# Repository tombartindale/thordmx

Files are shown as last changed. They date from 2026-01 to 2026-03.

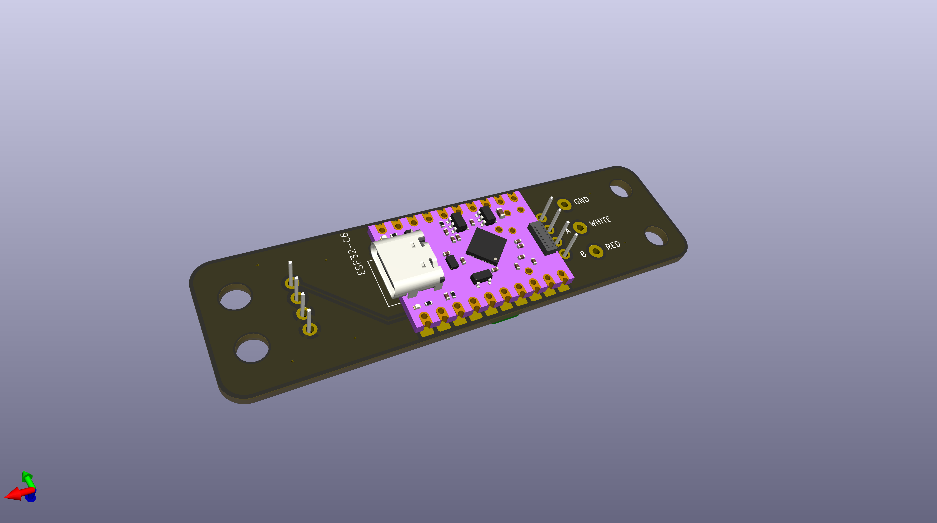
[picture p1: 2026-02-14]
docs/images/dmx_rec_bottom.png

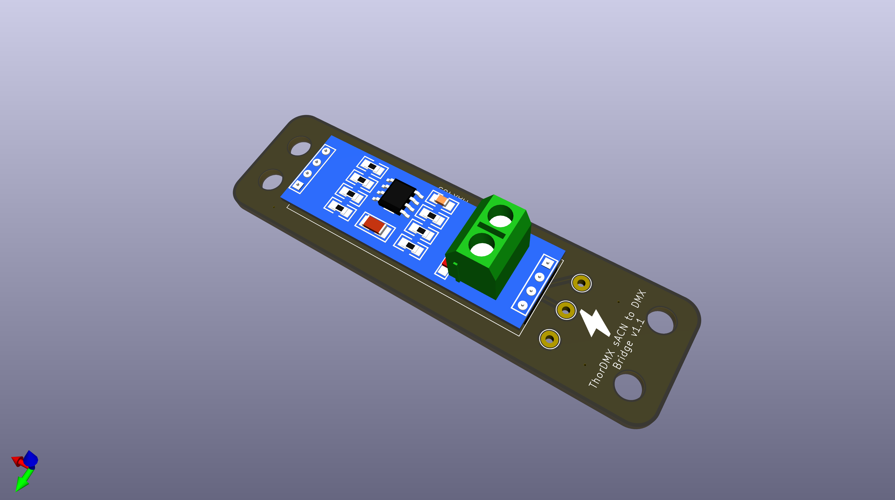
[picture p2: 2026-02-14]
docs/images/dmx_rec_top.png

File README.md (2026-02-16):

# ThorDMX Bridge System

> **Looking to build or set up a ThorDMX Bridge?** Check out the [User Documentation](https://tombartindale.github.io/thordmx/) for step-by-step guides on parts, assembly, firmware, and configuration.

A complete solution for wirelessly bridging sACN (E1.31) lighting data to DMX512 fixtures. The system consists of ESP32-based hardware devices and cross-platform management software for deploying and managing fleets of DMX bridges in professional lighting environments.

## Overview

The ThorDMX Bridge System enables lighting technicians to:

- **Receive sACN over WiFi** and output standard DMX512 signals
- **Discover and configure** multiple bridge devices from a single application
- **Provision new devices** by connecting to their WiFi access points
- **Monitor fleet health** with real-time status updates
- **Update firmware remotely** across multiple devices simultaneously

## Components

### Firmware (`/firmware`)

ESP32-C6 Arduino firmware that runs on the physical DMX bridge hardware.

**Key Features:**

- Receives sACN (E1.31) multicast packets over WiFi
- Outputs DMX512 signal via MAX485 transceiver (GPIO 0)
- Access Point mode for initial configuration with captive portal
- mDNS service advertisement (`_sacn-dmx._tcp`) for network discovery
- JSON REST API for remote configuration and monitoring
- OTA firmware updates with automatic rollback on failure
- WS2812 status LED for visual device state indication
- Serial interface for bulk provisioning during deployment

**Hardware Requirements:**

- ESP32-C6 microcontroller
- MAX485 differential transceiver for DMX output
- WS2812 RGB LED for status indication

**API Endpoints:**
| Endpoint | Method | Description |
|---|---|---|
| `/api/status` | GET | Device status and diagnostics |
| `/api/config` | GET/POST | Read or update configuration |
| `/api/reboot` | POST | Restart the device |
| `/api/identify` | POST | Flash LED for physical identification |
| `/api/firmware` | GET/POST | Firmware info and OTA updates |
| `/api/firmware/rollback` | POST | Revert to previous firmware |

---

### DMX Manager (`/dmx-manager`)

Cross-platform Electron desktop application for managing fleets of DMX bridge devices.

**Key Features:**

- **Automatic Discovery**: Finds devices on the network via mDNS
- **AP Provisioning**: Scans for unconfigured device access points and provisions them with WiFi credentials
- **Batch Configuration**: Configure multiple devices simultaneously with templated naming
- **Fleet Monitoring**: Real-time dashboard showing device health, signal strength, and sACN status
- **Remote Firmware Updates**: OTA flash multiple devices with progress tracking
- **Credential Auto-fill**: Retrieves current WiFi password from system keychain for easy provisioning

**Technology Stack:**

- Electron (cross-platform desktop)
- Vue 3 with TypeScript
- Tailwind CSS (dark mode optimized for lighting environments)
- Pinia for state management
- Native WiFi APIs (CoreWLAN on macOS, netsh on Windows, NetworkManager on Linux)

**Supported Platforms:**

- macOS 11+
- Windows 10+
- Linux (Ubuntu 20.04+)

---

### Simulator (`/simulator`)

A Node.js-based simulator for testing the DMX Manager application without physical hardware.

**Key Features:**

- Simulates multiple DMX bridge devices with full API compatibility
- mDNS service advertisement for discovery testing
- Fault injection for testing error handling scenarios
- Interactive CLI for runtime control
- Predefined scenarios for common testing situations

**Predefined Scenarios:**
| Scenario | Description |
|---|---|
| `single-device` | One healthy device |
| `three-devices` | Three devices on different universes |
| `ten-devices` | Load testing with 10 devices |
| `mixed-health` | Mix of healthy and faulty devices |
| `production-like` | Realistic 8-device deployment |
| `signal-loss` | Devices losing sACN signal |
| `high-latency` | 2-second response delays |
| `network-timeout` | Non-responsive devices |

**Quick Start:**

```bash
cd simulator
npm install
npm run dev -- --scenario three-devices
```

---

## Getting Started

### Running the Manager Application

```bash
cd dmx-manager
npm install
npm run dev
```

### Flashing Firmware to Hardware

1. Open `/firmware/DMX_Receiver` in Arduino IDE or PlatformIO
2. Select ESP32-C6 as the target board
3. Upload to your device
4. On first boot, the device creates an access point named `THOR-BRIDGE-XXXX`
5. Use the DMX Manager app to provision the device with your WiFi credentials

### Using the Simulator for Development

```bash
cd simulator
npm install
npm run dev -- --scenario production-like
```

The simulator will advertise devices via mDNS, which the DMX Manager will automatically discover.

---

## Specifications

Detailed technical specifications are available in the `/specs` directory:

- **[sacn-dmx-spec.md](specs/sacn-dmx-spec.md)** - Firmware technical specification
- **[dmx-manager-app-spec.md](specs/dmx-manager-app-spec.md)** - Manager application specification

---

## Project Structure

```
DMX_Receiver/
├── firmware/           # ESP32 Arduino firmware
│   └── DMX_Receiver/   # Main firmware sketch
├── dmx-manager/        # Electron desktop application
│   ├── electron/       # Main process (discovery, WiFi control)
│   └── src/            # Vue frontend
├── simulator/          # Device simulator for testing
│   └── src/            # Simulator source
└── specs/              # Technical specifications
```

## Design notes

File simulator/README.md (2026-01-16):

# DMX Receiver Simulator

A configurable simulator for testing the dmx-manager application. Simulates multiple DMX receiver devices with full JSON API and mDNS support, including fault injection for testing error scenarios.

## Quick Start

```bash
cd simulator
npm install
npm run dev
```

This starts 3 simulated devices by default.

## Usage

### Command Line Options

```bash
# Load a predefined scenario
npm run dev -- --scenario production-like

# Create custom number of devices
npm run dev -- --devices 10

# Custom starting port (default: 8080)
npm run dev -- --devices 5 --port 9000

# Disable mDNS (useful when running multiple simulators)
npm run dev -- --scenario three-devices --no-mdns
```

### Predefined Scenarios

| Scenario | Description | Devices |
|---|---|---|
| `single-device` | One healthy device | 1 |
| `three-devices` | Three devices on different universes | 3 |
| `ten-devices` | Load testing setup | 10 |
| `signal-loss` | Devices losing sACN signal | 2 |
| `packet-drop` | 30% packet drop rate | 2 |
| `high-latency` | 2 second response delay | 2 |
| `network-timeout` | Devices that don't respond | 2 |
| `packet-errors` | Corrupted sACN packets | 2 |
| `unstable` | Random device reboots | 2 |
| `low-memory` | Heap exhaustion simulation | 1 |
| `mixed-health` | Mix of healthy and faulty devices | 5 |
| `production-like` | Realistic 8-device setup | 8 |

### Interactive Commands

Once running, you can control the simulator interactively:

```
list                  List all devices with status
scenarios             List available scenarios
load <scenario>       Switch to a different scenario
fault <id> <type>     Inject fault on a device
clear <id>            Clear faults on a device
clear-all             Clear all faults
signal-loss <id>      Simulate sACN signal loss
restore <id>          Restore signal/network
offline <id>          Take device completely offline
add [name] [universe] Add a new device
remove <id>           Remove a device
status <id>           Show full device status JSON
exit                  Stop simulator and exit
```

### Fault Types

| Type | Effect |
|---|---|
| `signal-loss` | Device stops receiving sACN, dmx_fps drops to 0 |
| `timeout` | Device stops responding to all HTTP requests |
| `slow` | 2 second delay on all responses |
| `drop` | 30% of requests are silently dropped |
| `errors` | 10% of sACN packets are marked as errors |

## API Endpoints

Each simulated device exposes the same API as the real firmware:

| Endpoint | Method | Description |
|---|---|---|
| `/api/status` | GET | Full device status |
| `/api/config` | GET | Device configuration |
| `/api/config` | POST | Update configuration |
| `/api/reboot` | POST | Trigger device reboot |
| `/api/identify` | POST | Flash LED for identification |
| `/api/firmware` | GET | Firmware info |
| `/api/firmware` | POST | Upload firmware (multipart) |
| `/api/firmware/rollback` | POST | Rollback to previous firmware |

### Example API Calls

```bash
# Get device status
curl http://localhost:8080/api/status

# Update universe
curl -X POST http://localhost:8080/api/config \
  -H "Content-Type: application/json" \
  -d '{"sacn_universe": 5}'

# Identify device (flash LED for 10 seconds)
curl -X POST http://localhost:8080/api/identify \
  -H "Content-Type: application/json" \
  -d '{"duration": 10}'

# Reboot device
curl -X POST http://localhost:8080/api/reboot
```

## mDNS Discovery

Devices advertise themselves via mDNS as `_sacn-dmx._tcp` services.

```bash
# macOS
dns-sd -B _sacn-dmx._tcp local

# Linux
avahi-browse -rt _sacn-dmx._tcp
```

Each service includes TXT records:
- `universe` - sACN universe number
- `mac` - Device MAC address
- `version` - Firmware version

## Programmatic Usage

You can also use the simulator as a library in your tests:

```typescript
import { DmxReceiverSimulator } from './simulator.js';

const simulator = new DmxReceiverSimulator({
  basePort: 8080,
  enableMdns: true,
});

// Load a scenario
await simulator.loadScenario('three-devices');

// Or create custom devices
await simulator.addDevice({
  name: 'Test-Device',
  universe: 1,
});

// Inject faults
simulator.setDeviceFault(deviceId, {
  sacnSignalLoss: true,
});

// Clear faults
simulator.clearDeviceFault(deviceId);

// Get device info
const devices = simulator.getDevices();

// Cleanup
await simulator.stop();
simulator.destroy();
```

## Test Scenarios

### Testing Device Discovery

```bash
npm run dev -- --scenario three-devices
```

Then open dmx-manager - it should discover all 3 devices via mDNS.

### Testing Error Handling

```bash
npm run dev -- --scenario mixed-health
```

This creates 5 devices with various faults to test how the manager handles:
- Healthy devices (2)
- Signal loss (1)
- Slow responses (1)
- Packet drops (1)

### Testing Bulk Operations

```bash
npm run dev -- --devices 20
```

Use to test batch configuration updates and firmware upgrades.

### Testing Offline Recovery

```bash
# Start simulator
npm run dev -- --scenario three-devices

# Take a device offline
simulator> offline stage-left

# Verify manager shows device as offline
# Then restore it
simulator> restore stage-left
```

## Development

```bash
# Build TypeScript
npm run build

# Run from compiled JS
npm start

# Run directly with tsx
npm run dev
```

## Architecture

```
simulator/
├── src/
│   ├── index.ts           # CLI entry point
│   ├── simulator.ts       # Main simulator orchestrator
│   ├── simulated-device.ts # Device state machine
│   ├── device-server.ts   # Express HTTP server per device
│   ├── mdns-advertiser.ts # Bonjour mDNS service
│   ├── scenarios.ts       # Predefined test scenarios
│   └── types.ts           # TypeScript interfaces
├── package.json
├── tsconfig.json
└── README.md
```

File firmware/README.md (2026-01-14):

# sACN to DMX Bridge

A wireless sACN (E1.31) to DMX512 bridge built on the ESP32-C6 microcontroller. The device receives sACN packets over WiFi and outputs a standard DMX512 signal for controlling lighting fixtures.

## Features

- **WiFi Connectivity**: Automatic AP mode fallback with captive portal for easy setup
- **SmartConfig Support**: Bulk provisioning using ESP-Touch protocol
- **Serial Configuration**: Command-line interface for manufacturing and bulk deployment
- **sACN/E1.31 Reception**: Standard multicast sACN with priority handling
- **DMX512 Output**: Full 512-channel DMX at 40Hz refresh rate
- **JSON REST API**: Complete control and monitoring via HTTP
- **OTA Updates**: Over-the-air firmware updates with automatic rollback
- **mDNS Discovery**: Easy network discovery via Bonjour/Avahi
- **Status LED**: WS2812 RGB LED for visual status indication

## Hardware Requirements

- **Microcontroller**: ESP32-C6
- **DMX Output**: GPIO 0 connected to MAX485 transceiver (DI pin)
- **Status LED**: WS2812 RGB LED on GPIO 8
- **Power**: 5V USB or external power supply

## Arduino IDE Setup

### 1. Install ESP32 Board Support

1. Open Arduino IDE
2. Go to **File → Preferences**
3. Add this URL to "Additional Board Manager URLs":
   ```
   https://espressif.github.io/arduino-esp32/package_esp32_index.json
   ```
4. Go to **Tools → Board → Boards Manager**
5. Search for "esp32" and install **esp32 by Espressif Systems**
6. Select **Tools → Board → ESP32 Arduino → ESP32C6 Dev Module**

### 2. Install Required Libraries

Open **Tools → Manage Libraries** and install:

- **ArduinoJson** by Benoit Blanchon (v6.x or later)
- **FastLED** by Daniel Garcia
- **sACN** by sstaub (https://github.com/sstaub/sACN) - Install from ZIP or Git URL

**Note**: The following libraries are built-in with ESP32 Arduino core:
- WiFi
- WebServer
- ESPmDNS
- Preferences
- Update
- esp_dmx

### 3. Board Configuration

Set the following in Arduino IDE under **Tools**:

- **Board**: ESP32C6 Dev Module
- **Upload Speed**: 921600
- **USB CDC On Boot**: Enabled
- **Flash Size**: 4MB (or your board's flash size)
- **Partition Scheme**: Minimal SPIFFS (1.9MB APP with OTA/190KB SPIFFS)

## Building and Uploading

1. Open `DMX_Receiver.ino` in Arduino IDE
2. Connect your ESP32-C6 via USB
3. Select the correct COM port under **Tools → Port**
4. Click **Upload** button or press `Ctrl+U`

## First-Time Setup

### Method 1: Captive Portal (Recommended for Single Device)

1. Power on the device
2. The device will create a WiFi network named `DMX-Bridge-XXXX` (where XXXX is the last 4 digits of MAC address)
3. Connect to this network from your phone or computer
4. A configuration page should open automatically (or navigate to `192.168.4.1`)
5. Enter your WiFi credentials and desired sACN universe
6. Click "Save & Connect"
7. The device will reboot and connect to your network

### Method 2: SmartConfig (For Multiple Devices)

1. Power on all unconfigured devices
2. Download ESP-Touch app:
   - **iOS**: [EspressifTouchV2](https://apps.apple.com/app/espressif-esptouch/id1071176700)
   - **Android**: [EspTouch](https://github.com/EspressifApp/EsptouchForAndroid/releases)
3. Connect your phone to the target WiFi network
4. Open the app and enter WiFi credentials
5. Press "Confirm" to broadcast credentials
6. All devices will receive credentials and connect
7. Configure individual universe numbers via API or serial

### Method 3: Serial Configuration (For Manufacturing)

1. Connect device via USB
2. Open Serial Monitor at 115200 baud
3. Send configuration command:
   ```
   CONFIG:{"wifi_ssid":"YourNetwork","wifi_password":"password123","sacn_universe":1,"device_name":"Stage-Left"}
   ```
4. Device will save settings and reboot

#### Serial Commands

- `STATUS` - Get current device status
- `CONFIG:{json}` - Update configuration
- `REBOOT` - Restart device
- `FACTORY_RESET` - Clear all settings and reboot

## Usage

### Finding Your Device

After connecting to WiFi, find your device using:

**macOS/Linux:**
```bash
dns-sd -B _sacn-dmx._tcp local
```

**Or access directly:**
```
http://dmx-bridge-xxxx.local/api/status
```

### API Endpoints

#### GET /api/status
Returns comprehensive device status including WiFi, sACN stats, and system info.

```bash
curl http://dmx-bridge-xxxx.local/api/status
```

#### GET /api/config
Returns current configuration (WiFi SSID, universe, device name).

```bash
curl http://dmx-bridge-xxxx.local/api/config
```

#### POST /api/config
Update device configuration.

```bash
curl -X POST http://dmx-bridge-xxxx.local/api/config \
  -H "Content-Type: application/json" \
  -d '{"sacn_universe":2,"device_name":"Stage-Right"}'
```

#### POST /api/reboot
Reboot the device.

```bash
curl -X POST http://dmx-bridge-xxxx.local/api/reboot
```

#### POST /api/firmware
Upload new firmware for OTA update.

```bash
curl -X POST -F "firmware=@firmware.bin" http://dmx-bridge-xxxx.local/api/firmware
```

#### POST /api/firmware/rollback
Rollback to previous firmware version.

```bash
curl -X POST http://dmx-bridge-xxxx.local/api/firmware/rollback
```

## LED Status Indicators

| State | LED Behavior |
|---|---|
| AP mode active | Pulsing blue (1 second cycle) |
| Connecting to WiFi | Pulsing yellow (0.5 second cycle) |
| Connected successfully | Solid green for 2 seconds, then off |
| Receiving sACN | Off (normal operation) |
| WiFi connection lost | Solid red |
| SmartConfig listening | Pulsing blue |
| SmartConfig received | Two rapid green flashes |

## Troubleshooting

### Device Won't Connect to WiFi

1. Try factory reset: Send `FACTORY_RESET` via serial
2. Check WiFi credentials are correct
3. Ensure 2.4GHz network (ESP32 doesn't support 5GHz)
4. Check signal strength (should be >-70 dBm)

### No DMX Output

1. Verify MAX485 transceiver connections:
   - ESP32 GPIO 0 → MAX485 DI
   - MAX485 DE and RE tied together (to GPIO or high)
   - MAX485 A and B to DMX connector
2. Check DMX cable polarity
3. Verify sACN packets are being sent to correct universe
4. Check `/api/status` for `sacn_packets_received` counter

### Can't Access Web Interface

1. Ensure device is connected to network (LED should be off, not pulsing)
2. Try accessing by IP instead of hostname
3. Check mDNS is working: `ping dmx-bridge-xxxx.local`
4. Firewall may be blocking port 80

### OTA Update Fails

1. Ensure firmware binary is valid (.bin file from Arduino IDE)
2. Check available heap: should be >100KB free
3. Try smaller firmware or different partition scheme
4. Power cycle and try again

## Development

### Project Structure

```
DMX_Receiver/
├── DMX_Receiver.ino         # Main sketch with setup() and loop()
├── wifi_manager.ino         # WiFi and SmartConfig handling
├── serial_config.ino        # Serial command interface
├── sacn_receiver.ino        # sACN/E1.31 packet processing
├── dmx_output.ino           # DMX512 transmission
├── api_server.ino           # JSON REST API endpoints
├── captive_portal.ino       # HTML captive portal
├── led_controller.ino       # WS2812 status LED
└── README.md                # This file
```

### Task Architecture

The application uses FreeRTOS tasks for concurrent operation:

1. **WiFi Task** (Core 0) - Connection management, AP mode, SmartConfig
2. **sACN Task** (Core 1) - UDP multicast reception and parsing
3. **DMX Task** (Core 1) - DMX512 frame transmission at 40Hz
4. **LED Task** (Core 0) - Status LED animation
5. **Serial Task** (Core 0) - Serial command processing

### Memory Considerations

- DMX buffer: 512 bytes (shared between sACN and DMX tasks)
- Task stacks: ~24KB total
- HTTP server buffer: ~4KB
- sACN library: ~8KB
- Minimum free heap during operation: ~100KB

## License

This project is provided as-is for educational and commercial use.

## Credits

- **ESPAsyncE131** library by forkineye
- **FastLED** library by Daniel Garcia
- **ArduinoJson** library by Benoit Blanchon
- **esp_dmx** library (ESP32 Arduino Core)

## Support

For issues, questions, or contributions, please refer to the specification document: `sacn-dmx-spec.md`

## Version History

- **1.0.0** - Initial release
  - WiFi connectivity with AP fallback
  - SmartConfig provisioning
  - Serial configuration interface
  - sACN/E1.31 reception
  - DMX512 output
  - JSON REST API
  - OTA firmware updates
  - mDNS discovery
  - WS2812 status LED

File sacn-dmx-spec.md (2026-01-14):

# sACN to DMX Bridge — Technical Specification

## Overview

A wireless sACN (E1.31) to DMX512 bridge built on the ESP32-C6 microcontroller. The device receives sACN packets over WiFi and outputs a standard DMX512 signal for controlling lighting fixtures.

## Hardware Platform

- **Microcontroller:** ESP32-C6
- **Development framework:** Arduino (ESP32 Arduino Core)
- **DMX output pin:** GPIO 0 (directly feeds a MAX485 differential transceiver)
- **Status LED:** WS2812 RGB LED on GPIO 8

## Functional Requirements

### F1: WiFi Connectivity

- **F1.1:** On first boot or when no known network is available, the device shall enter Access Point (AP) mode.
- **F1.2:** AP mode SSID shall be `DMX-Bridge-XXXX` where `XXXX` is the last four hexadecimal digits of the device MAC address.
- **F1.3:** The AP shall be open (no password) for ease of initial configuration.
- **F1.4:** In AP mode, the device shall serve a captive portal on `192.168.4.1` presenting a web form to configure WiFi credentials and sACN universe.
- **F1.5:** Upon successful configuration, credentials shall be saved and the device shall reboot into station mode.
- **F1.6:** The device shall automatically reconnect to the configured network on subsequent power cycles.
- **F1.7:** If the configured network becomes unavailable, the device shall retry connection for 30 seconds, then fall back to AP mode.

### F1A: Serial Configuration Interface

A serial interface for bulk provisioning during manufacturing or deployment.

- **F1A.1:** The device shall listen on the USB serial port at 115200 baud for configuration commands.
- **F1A.2:** Serial configuration shall be available in all device states (AP mode, connecting, connected).
- **F1A.3:** The device shall accept a JSON configuration object as a single line of text.

**Serial command format:**
```
CONFIG:{"wifi_ssid":"NetworkName","wifi_password":"password123","sacn_universe":1,"device_name":"Stage-Left"}
```

- **F1A.4:** All fields in the JSON object are optional. Only provided fields shall be updated.
- **F1A.5:** The device shall respond with a JSON status line:

**Success response:**
```
OK:{"message":"Configuration saved","reboot_required":true}
```

**Error response:**
```
ERROR:{"message":"Invalid JSON format"}
```

- **F1A.6:** If WiFi credentials are changed, the device shall automatically reboot 2 seconds after sending the success response.
- **F1A.7:** The device shall also accept the following serial commands:
  - `STATUS` — returns current device status as JSON (same format as GET /api/status)
  - `REBOOT` — triggers immediate device restart
  - `FACTORY_RESET` — clears all saved configuration and reboots into AP mode

**Example provisioning session:**
```
> STATUS
< OK:{"device_name":"DMX-Bridge-A1B2","wifi_connected":false,"sacn_universe":1,...}
> CONFIG:{"wifi_ssid":"VenueWiFi","wifi_password":"secret","sacn_universe":5}
< OK:{"message":"Configuration saved","reboot_required":true}
< REBOOTING...
```

### F1B: SmartConfig Provisioning

Support for Espressif SmartConfig (ESP-Touch) protocol for bulk WiFi provisioning.

- **F1B.1:** When in AP mode, the device shall simultaneously listen for SmartConfig broadcasts.
- **F1B.2:** SmartConfig shall use the ESP-Touch V2 protocol (AES encrypted).
- **F1B.3:** Upon receiving valid SmartConfig credentials, the device shall:
  1. Save the WiFi credentials to NVS
  2. Flash the status LED green twice rapidly to confirm receipt
  3. Reboot and attempt connection to the provided network
- **F1B.4:** SmartConfig shall have a 2-minute timeout when in AP mode. After timeout, the device remains in AP mode and restarts SmartConfig listening.
- **F1B.5:** SmartConfig only provisions WiFi credentials. Other settings (universe, device name) must be configured via API or serial after network connection.

**LED behaviour during SmartConfig:**
| State | LED Behaviour |
|---|---|
| Listening for SmartConfig | Pulsing blue (same as AP mode) |
| SmartConfig credentials received | Two rapid green flashes, then reboot |

**Provisioning workflow for multiple devices:**
1. Power on all unconfigured devices (all enter AP mode, listening for SmartConfig)
2. Use ESP-Touch app (iOS/Android) or esptool to broadcast credentials
3. All devices receive credentials simultaneously and reboot
4. Use JSON API discovery (mDNS) to find devices and configure universes/names

### F2: sACN Reception

The device shall use the ESPAsyncE131 library (https://github.com/forkineye/ESPAsyncE131) for sACN packet handling.

- **F2.1:** The device shall listen for E1.31 (sACN) multicast packets on the standard port (5568).
- **F2.2:** The device shall subscribe to the multicast group for the configured universe (default: universe 1).
- **F2.3:** Supported universe range: 1–63999.
- **F2.4:** The device shall extract all 512 DMX channel values from received sACN packets.
- **F2.5:** The device shall handle sACN priority correctly — if packets from multiple sources are received, the highest priority source shall take precedence.
- **F2.6:** If sACN packets stop arriving, the device shall hold the last received DMX values indefinitely (no timeout fade).

**ESPAsyncE131 usage notes:**
- Use multicast mode (`E131_MULTICAST`) for standard sACN reception.
- The library handles universe subscription and multicast group joining automatically.
- Access packet data via `e131.data` array after checking `e131.isEmpty()`.
- Source name available via `e131.packet->source_name` for status reporting.

### F3: DMX Output

- **F3.1:** The device shall output a DMX512 signal conforming to ANSI E1.11 (DMX512-A).
- **F3.2:** Output shall be on GPIO 0, driving a MAX485 transceiver.
- **F3.3:** All 512 channels shall be transmitted in each DMX packet.
- **F3.4:** DMX refresh rate shall be approximately 40Hz (~25ms per frame).
- **F3.5:** DMX output shall begin immediately on boot with all channels at zero until sACN data is received.

### F3A: mDNS Discovery

The device shall advertise itself via mDNS (Bonjour/Avahi) for easy discovery on the network.

- **F3A.1:** The device shall advertise an mDNS hostname of `{device_name}.local` (e.g., `dmx-bridge-a1b2.local`).
- **F3A.2:** The device shall advertise a service of type `_sacn-dmx._tcp` on port 80.
- **F3A.3:** The service TXT record shall include:
  - `universe={configured_universe}` — current sACN universe
  - `mac={mac_address}` — device MAC address
  - `version={firmware_version}` — firmware version string

**Example mDNS advertisement:**
```
Service: _sacn-dmx._tcp.local
Host: dmx-bridge-a1b2.local
Port: 80
TXT: universe=1, mac=AA:BB:CC:DD:A1:B2, version=1.0.0
```

- **F3A.4:** mDNS shall be active whenever the device is connected to WiFi in station mode.
- **F3A.5:** The hostname shall update if the device name is changed (requires reboot).

**Discovery commands:**

On macOS/Linux:
```bash
dns-sd -B _sacn-dmx._tcp local
# or
avahi-browse -rt _sacn-dmx._tcp
```

On Windows (with Bonjour installed):
```bash
dns-sd -B _sacn-dmx._tcp local
```

**Programmatic discovery (Python example):**
```python
from zeroconf import ServiceBrowser, Zeroconf

class Listener:
    def add_service(self, zc, type, name):
        info = zc.get_service_info(type, name)
        print(f"Found: {info.server} at {info.parsed_addresses()[0]}")
        print(f"  Universe: {info.properties[b'universe'].decode()}")

zeroconf = Zeroconf()
browser = ServiceBrowser(zeroconf, "_sacn-dmx._tcp.local.", Listener())
```

### F4: Configuration Persistence

- **F4.1:** All configuration settings shall be stored in non-volatile storage (NVS/flash).
- **F4.2:** Persisted settings include:
  - WiFi SSID
  - WiFi password
  - sACN universe number
  - Device name
- **F4.3:** Settings shall survive power cycles and firmware updates where possible.

### F5: JSON API

The device shall expose an HTTP JSON API on port 80 when connected to WiFi in station mode.

#### F5.1: GET /api/status

Returns current device status including diagnostic information.

**Response:**
```json
{
  "device_name": "DMX-Bridge-A1B2",
  "firmware_version": "1.0.0",
  "wifi_connected": true,
  "wifi_ssid": "LightingNetwork",
  "wifi_rssi": -52,
  "wifi_signal_quality": "good",
  "ip_address": "192.168.1.50",
  "mac_address": "AA:BB:CC:DD:A1:B2",
  "sacn_universe": 1,
  "sacn_packets_received": 123456,
  "sacn_packets_errors": 12,
  "sacn_source_ip": "192.168.1.10",
  "sacn_source_name": "ETC Eos",
  "sacn_priority": 100,
  "last_packet_ms_ago": 12,
  "dmx_fps": 40,
  "uptime_seconds": 3600,
  "free_heap_bytes": 180000,
  "min_free_heap_bytes": 165000,
  "cpu_temperature_c": 42.5,
  "reboot_count": 3,
  "last_reboot_reason": "power_on"
}
```

**Field descriptions:**

| Field | Description |
|---|---|
| `wifi_rssi` | WiFi signal strength in dBm (typical range: -30 excellent to -90 poor) |
| `wifi_signal_quality` | Human-readable signal quality: "excellent" (>-50), "good" (-50 to -60), "fair" (-60 to -70), "poor" (<-70) |
| `sacn_packets_errors` | Count of malformed or dropped sACN packets since boot |
| `sacn_priority` | Priority value from current sACN source (0-200) |
| `dmx_fps` | Actual DMX output frames per second (rolling average) |
| `free_heap_bytes` | Current free heap memory in bytes |
| `min_free_heap_bytes` | Lowest free heap since boot (indicates memory pressure) |
| `cpu_temperature_c` | ESP32 internal temperature sensor reading (if available) |
| `reboot_count` | Number of reboots since factory reset (stored in NVS) |
| `last_reboot_reason` | Reason for last reboot: "power_on", "software", "watchdog", "crash", "brownout" |

#### F5.2: GET /api/config

Returns current configuration.

**Response:**
```json
{
  "device_name": "DMX-Bridge-A1B2",
  "sacn_universe": 1,
  "wifi_ssid": "LightingNetwork"
}
```

Note: WiFi password shall never be returned by the API.

#### F5.3: POST /api/config

Batch update configuration settings.

**Request body (all fields optional):**
```json
{
  "device_name": "Stage-Left-DMX",
  "sacn_universe": 2,
  "wifi_ssid": "NewNetwork",
  "wifi_password": "newpassword123"
}
```

**Response:**
```json
{
  "success": true,
  "message": "Configuration updated. Reboot required for WiFi changes.",
  "reboot_required": true
}
```

**Validation:**
- `sacn_universe`: integer, 1–63999
- `device_name`: string, 1–32 characters, alphanumeric and hyphens only
- `wifi_ssid`: string, 1–32 characters
- `wifi_password`: string, 8–63 characters (WPA2 requirement)

#### F5.4: POST /api/reboot

Triggers a device restart.

**Request body:** None required.

**Response:**
```json
{
  "success": true,
  "message": "Rebooting in 1 second."
}
```

The device shall delay 1 second before rebooting to allow the HTTP response to complete.

#### F5.5: POST /api/firmware

Upload new firmware binary to update the device.

**Request:**
- Content-Type: `multipart/form-data`
- Field name: `firmware`
- File: compiled firmware binary (.bin file)

**Example using curl:**
```bash
curl -X POST -F "firmware=@firmware_v1.1.0.bin" http://dmx-bridge-a1b2.local/api/firmware
```

**Response (success):**
```json
{
  "success": true,
  "message": "Firmware uploaded successfully. Validating...",
  "new_version": "1.1.0",
  "previous_version": "1.0.0",
  "rebooting": true
}
```

**Response (validation failed):**
```json
{
  "success": false,
  "error": "Firmware validation failed: invalid magic bytes"
}
```

**Update process:**
1. Device receives firmware binary and writes to OTA partition.
2. Device validates firmware (magic bytes, size, checksum if available).
3. If valid, device marks new partition as bootable and stores current version for rollback.
4. Device responds with success and reboots after 2 seconds.
5. On first boot after update, device runs self-test (WiFi connects, DMX output starts).
6. If self-test passes, update is marked as confirmed.
7. If self-test fails or device crashes within 60 seconds, watchdog triggers rollback.

**Validation checks:**
- Firmware binary has valid ESP32 application header
- Binary size is within flash partition limits
- Optional: SHA256 checksum if provided in request

#### F5.6: POST /api/firmware/rollback

Manually trigger a rollback to the previous firmware version.

**Request body:** None required.

**Response (success):**
```json
{
  "success": true,
  "message": "Rolling back to previous firmware",
  "current_version": "1.1.0",
  "rollback_version": "1.0.0",
  "rebooting": true
}
```

**Response (no rollback available):**
```json
{
  "success": false,
  "error": "No previous firmware available for rollback"
}
```

#### F5.7: GET /api/firmware

Returns current firmware information and rollback status.

**Response:**
```json
{
  "current_version": "1.1.0",
  "previous_version": "1.0.0",
  "rollback_available": true,
  "last_update": "2024-01-15T14:32:00Z",
  "update_confirmed": true,
  "partition_scheme": "ota_0 (active), ota_1 (previous)"
}
```

#### F5.8: API Error Handling

All error responses shall use appropriate HTTP status codes and include a JSON body:

```json
{
  "success": false,
  "error": "Invalid universe number. Must be 1-63999."
}
```

| Scenario | HTTP Status |
|---|---|
| Malformed JSON | 400 |
| Invalid parameter value | 400 |
| Endpoint not found | 404 |
| Internal error | 500 |

### F6: Status LED Behaviour

The WS2812 LED on GPIO 8 shall indicate device state as follows:

| State | LED Behaviour |
|---|---|
| AP mode active | Pulsing blue (1 second cycle) |
| Connecting to WiFi | Pulsing yellow (0.5 second cycle) |
| Connected, awaiting first sACN packet | Solid green for 2 seconds, then off |
| Receiving sACN normally | Off |
| WiFi connection lost | Solid red until reconnected or AP mode entered |
| Error (unrecoverable) | Fast flashing red (4Hz) |

**Rationale:** In normal installed operation, the LED remains off to avoid unwanted light pollution in performance environments.

### F7: Captive Portal Web Interface

The captive portal served in AP mode shall provide a minimal, functional HTML form.

#### F7.1: Page Structure

- Device name/identifier displayed at top
- Current firmware version displayed
- Form fields:
  - WiFi SSID (text input, required)
  - WiFi Password (password input, required)
  - sACN Universe (number input, default 1, range 1–63999)
- Submit button labelled "Save & Connect"

#### F7.2: Behaviour

- On submission, validate inputs client-side where practical.
- Display success message and indicate device will reboot.
- Device saves settings and reboots after 2 seconds.

#### F7.3: Styling

- Simple, functional appearance suitable for mobile browsers.
- No external CSS or JavaScript dependencies (fully self-contained).

## Non-Functional Requirements

### NF1: Performance

- **NF1.1:** sACN packet processing latency shall be <5ms from packet receipt to DMX output update.
- **NF1.2:** The device shall handle sACN packets at up to 44Hz without packet loss.
- **NF1.3:** DMX output shall be jitter-free under normal operation.

### NF2: Reliability

- **NF2.1:** The device shall operate continuously without requiring manual restart.
- **NF2.2:** The device shall recover gracefully from temporary WiFi dropouts.
- **NF2.3:** Watchdog timer shall be enabled to recover from software hangs.

### NF3: Memory

- **NF3.1:** RAM usage shall remain stable over time (no memory leaks).
- **NF3.2:** The application shall fit within the ESP32-C6 flash constraints.
- **NF3.3:** Flash partition layout shall include two OTA partitions for firmware updates and rollback capability.

## Software Architecture

### Recommended Task Structure

The application should use FreeRTOS tasks (available via Arduino ESP32 core):

1. **WiFi Management Task** — handles connection, reconnection, AP mode fallback, and SmartConfig listening.
2. **sACN Receiver Task** — listens for UDP multicast, parses E1.31 packets, updates DMX buffer.
3. **DMX Output Task** — continuously transmits DMX frames from buffer at 40Hz.
4. **HTTP Server Task** — serves API endpoints and captive portal.
5. **LED Controller Task** — manages WS2812 status indication.
6. **Serial Command Task** — monitors USB serial for configuration commands.

### Shared Data

- A 512-byte DMX channel buffer shared between sACN receiver and DMX output.
- Use mutex or atomic operations to prevent torn reads/writes.

### Recommended Libraries

| Function | Suggested Library |
|---|---|
| WiFi & AP mode | Built-in WiFi.h |
| SmartConfig | Built-in WiFi.h (WiFi.beginSmartConfig()) |
| mDNS | ESPmDNS (built-in) |
| HTTP server | WebServer (built-in) or ESPAsyncWebServer |
| NVS storage | Preferences.h (built-in) |
| WS2812 LED | Adafruit NeoPixel or FastLED |
| sACN/E1.31 | ESPAsyncE131 (https://github.com/forkineye/ESPAsyncE131) |
| DMX output | esp_dmx or manual UART configuration |

Note: Evaluate library compatibility with ESP32-C6 specifically, as some older libraries may not support this chip.

## Pin Assignment Summary

| GPIO | Function |
|---|---|
| 0 | DMX output (TX to MAX485 DI pin) |
| 8 | WS2812 status LED data |

## Configuration Defaults

| Parameter | Default Value |
|---|---|
| sACN Universe | 1 |
| Device Name | `DMX-Bridge-XXXX` (from MAC) |
| DMX Refresh Rate | 40Hz |
| AP Mode IP | 192.168.4.1 |
| API Port | 80 |

## Testing Criteria

### TC1: WiFi Provisioning
- [ ] Device enters AP mode on first boot.
- [ ] Captive portal is accessible at 192.168.4.1.
- [ ] WiFi credentials can be submitted and are saved.
- [ ] Device connects to configured network after reboot.
- [ ] Device falls back to AP mode if configured network unavailable.

### TC1A: Serial Configuration
- [ ] Device accepts CONFIG command with valid JSON.
- [ ] Device rejects malformed JSON with appropriate error.
- [ ] STATUS command returns current device state.
- [ ] REBOOT command triggers restart.
- [ ] FACTORY_RESET clears all config and enters AP mode.
- [ ] Partial configuration updates only specified fields.
- [ ] Serial commands work in all device states.

### TC1B: SmartConfig Provisioning
- [ ] Device listens for SmartConfig while in AP mode.
- [ ] Device receives credentials from ESP-Touch app.
- [ ] LED flashes green twice on successful SmartConfig receipt.
- [ ] Device connects to network after SmartConfig provisioning.
- [ ] Multiple devices can be provisioned simultaneously.

### TC2: sACN Reception
- [ ] Device receives sACN packets on configured universe.
- [ ] Changing universe via API updates subscription correctly.
- [ ] Device handles standard sACN sources (ETC Eos, QLC+, etc.).
- [ ] Priority handling works when multiple sources transmit.

### TC3: DMX Output
- [ ] DMX output is valid per E1.11 (test with DMX analyser).
- [ ] All 512 channels are transmitted.
- [ ] Output updates promptly when sACN data changes.
- [ ] Output holds last values when sACN stops.

### TC4: JSON API
- [ ] GET /api/status returns correct information.
- [ ] GET /api/config returns current settings.
- [ ] POST /api/config updates settings correctly.
- [ ] POST /api/reboot triggers restart.
- [ ] Invalid requests return appropriate errors.

### TC5: Status LED
- [ ] LED pulses blue in AP mode.
- [ ] LED pulses yellow while connecting.
- [ ] LED shows green briefly on connection, then turns off.
- [ ] LED remains off during normal operation.
- [ ] LED shows red on connection loss.

## Future Considerations (Out of Scope)

The following features are not included in this specification but may be considered for future versions:

- RDM passthrough
- Multiple universe output
- Art-Net input support
- Static IP configuration
- Web-based DMX monitor/debug view
- Pull-based firmware updates (device fetches from URL)
- Log streaming endpoint for remote debugging

---

*Specification version: 1.0*
*Target platform: ESP32-C6 with Arduino framework*

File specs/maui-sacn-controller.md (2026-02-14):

# sACN Color Controller - .NET MAUI App Spec

## Overview

A minimal Android app built with .NET MAUI that sends sACN (E1.31) data to DMX receivers on the local network. The app presents a color wheel for selecting an RGB color, which is transmitted as channels 1 (Red), 2 (Green), and 3 (Blue) on universe 1.

## Platform

- **Framework:** .NET MAUI (.NET 8+)
- **Target:** Android (API 24+)
- **Future:** iOS support may be added later; keep platform-specific code isolated
- **IDE:** Visual Studio Code

## Development Environment

### Prerequisites

- .NET 8 SDK (or later)
- Android SDK (API 24+) — installed via Android SDK Manager or `dotnet workload install maui-android`
- Java JDK 17 (required by Android SDK tooling)

### VS Code Extensions

| Extension | ID | Purpose |
|---|---|---|
| C# Dev Kit | `ms-dotnettools.csdevkit` | Core C# language support, project system, solution explorer |
| .NET MAUI | `ms-dotnettools.dotnet-maui` | MAUI project templates, XAML IntelliSense, device targeting, debug/deploy |
| XAML | `ms-dotnettools.vscode-dotnet-runtime` | .NET runtime acquisition (dependency of above) |

### Workload Setup

```bash
dotnet workload install maui-android
```

### Build & Run

```bash
# Build
dotnet build -f net8.0-android

# Deploy to connected device / emulator
dotnet build -f net8.0-android -t:Run
```

### Debugging

- Use the **.NET MAUI** debug launch configuration in VS Code (provided by the MAUI extension)
- Select the target Android device/emulator from the MAUI device picker in the status bar

## Core Features

### 1. Color Wheel Input

- Full-screen color wheel (or color disc) as the primary UI element
- Touch-driven: drag finger across the wheel to select hue/saturation, with a brightness slider alongside
- Selection updates continuously as the user drags (no submit button)
- Display the selected color as a preview swatch and show the RGB values (0–255) as text beneath the wheel
- Responsive to screen size; wheel should fill available width

### 2. sACN Output

- Transmit E1.31 (sACN) multicast UDP packets on the standard multicast address for universe 1: `239.255.0.1`
- Port: `5568`
- Protocol details:
  - E1.31 data packet (vector `0x00000004`)
  - Root layer, framing layer, DMP layer per ANSI E1.31-2018
  - Universe: `1`
  - Priority: `100` (default)
  - Channel data: 512 bytes (slots), only slots 1–3 populated (R, G, B), remainder zero
  - Sequence number: increment per packet (0–255, wrapping)
  - Source name: `"MAUI sACN Controller"` (UTF-8, 64 bytes padded)
  - CID: generate once on first launch, persist in app preferences
- **Transmission rate:** send packets at ~22 Hz (every ~45 ms) while the color is changing, drop to ~1 Hz keep-alive when idle (no touch for >1 second)
- Use `System.Net.Sockets.UdpClient` for multicast UDP

### 3. Network Status Warning

- On launch and on resume, check for active Wi-Fi connectivity using MAUI's `Connectivity` API (`NetworkAccess` and `ConnectionProfiles`)
- If no Wi-Fi connection is detected, show a non-dismissable banner at the top of the screen: **"No Wi-Fi connection — sACN output disabled"**
- Disable packet transmission while Wi-Fi is unavailable
- Subscribe to `Connectivity.ConnectivityChanged` to update the banner in real time
- When Wi-Fi reconnects, dismiss the banner and resume transmission

## UI Layout

```
┌─────────────────────────────┐
│ ⚠ No Wi-Fi (if applicable) │  <- warning banner (yellow/orange)
├─────────────────────────────┤
│                             │
│                             │
│        Color Wheel          │  <- touch-interactive disc
│        (hue + sat)          │
│                             │
│                             │
├─────────────────────────────┤
│  ☀ Brightness Slider        │  <- horizontal slider (0–100%)
├─────────────────────────────┤
│  ┌──────┐  R: 255           │
│  │preview│  G: 128           │  <- color swatch + RGB readout
│  │swatch │  B: 0             │
│  └──────┘                   │
└─────────────────────────────┘
```

- Single page, no navigation
- Dark background (`#1E1E1E`) so colors stand out
- Minimal chrome — the color wheel is the hero element

## Project Structure

```
SacnController/
├── SacnController.csproj
├── App.xaml / App.xaml.cs
├── MauiProgram.cs
├── MainPage.xaml / MainPage.xaml.cs
├── Services/
│   ├── SacnService.cs            # packet building & UDP transmission
│   └── NetworkMonitorService.cs  # Wi-Fi connectivity monitoring
├── Controls/
│   └── ColorWheelView.cs         # custom SkiaSharp drawable for the wheel
├── Models/
│   └── RgbColor.cs               # simple R, G, B byte struct
├── Platforms/
│   └── Android/
│       └── AndroidManifest.xml
└── Resources/
```

## Dependencies

| Package | Purpose |
|---|---|
| `SkiaSharp.Views.Maui.Controls` | Rendering the color wheel via `SKCanvasView` + touch handling |
| None (built-in) | `System.Net.Sockets.UdpClient` for sACN UDP multicast |
| None (built-in) | `Microsoft.Maui.Networking.Connectivity` for Wi-Fi detection |

No third-party sACN library — the protocol is simple enough to implement directly in `SacnService`.

## Key Implementation Notes

### Color Wheel (SkiaSharp)

- Draw a circular HSV color disc using a sweep gradient (hue) combined with a radial gradient (saturation)
- Handle `SKTouchAction.Pressed`, `Moved`, `Released` to track finger position
- Convert polar coordinates (angle → hue, distance from center → saturation) to HSV, then combine with the brightness slider value to produce RGB
- Fire a `ColorChanged` event on every touch move

### sACN Packet Structure

Total packet size: 638 bytes (126 byte header + 512 slots). Build as a `byte[]`:

| Offset | Length | Field |
|---|---|---|
| 0–11 | 12 | Preamble + post-amble + ACN packet identifier |
| 12–15 | 4 | Root flags + length |
| 16–19 | 4 | Root vector (`0x00000004`) |
| 20–35 | 16 | CID (sender UUID) |
| 36–37 | 2 | Framing flags + length |
| 38–41 | 4 | Framing vector (`0x00000002`) |
| 42–105 | 64 | Source name (UTF-8 padded) |
| 106 | 1 | Priority (100) |
| 107–108 | 2 | Sync address (0) |
| 109 | 1 | Sequence number |
| 110 | 1 | Options |
| 111–112 | 2 | Universe (1) |
| 113–114 | 2 | DMP flags + length |
| 115 | 1 | DMP vector (`0x02`) |
| 116 | 1 | Address type (`0xA1`) |
| 117–118 | 2 | First property address (0) |
| 119–120 | 2 | Address increment (1) |
| 121–122 | 2 | Property value count (513) |
| 123 | 1 | DMX start code (0) |
| 124–635 | 512 | DMX channel data (slot 1 = R, 2 = G, 3 = B) |

### Android Permissions

In `AndroidManifest.xml`:
```xml
<uses-permission android:name="android.permission.INTERNET" />
<uses-permission android:name="android.permission.ACCESS_NETWORK_STATE" />
<uses-permission android:name="android.permission.ACCESS_WIFI_STATE" />
<uses-permission android:name="android.permission.CHANGE_WIFI_MULTICAST_STATE" />
```

Acquire a `WifiManager.MulticastLock` on Android to ensure multicast packets are not dropped by the Wi-Fi driver. Acquire on app resume, release on pause.

### Transmission Lifecycle

- Start sending when the app enters the foreground and Wi-Fi is available
- Use a background `Task` with a `PeriodicTimer` for the send loop
- While touch is active: send at ~22 Hz
- While idle: send at ~1 Hz (keep-alive to prevent receivers from timing out)
- Stop sending when the app enters the background or Wi-Fi is lost
- On app close/background: stop sending (receivers retain last received values)

## CI/CD — GitHub Actions

### Workflow: Build & Release on Tag Push

**Trigger:** Push of a tag matching `v*` (e.g. `v1.0.0`)

**File:** `.github/workflows/build-android.yml`

```yaml
name: Build Android APK

on:
  push:
    tags:
      - 'v*'

jobs:
  build:
    runs-on: ubuntu-latest

    steps:
      - name: Checkout
        uses: actions/checkout@v4

      - name: Setup .NET
        uses: actions/setup-dotnet@v4
        with:
          dotnet-version: '8.0.x'

      - name: Install MAUI workload
        run: dotnet workload install maui-android

      - name: Setup Java JDK
        uses: actions/setup-java@v4
        with:
          distribution: 'microsoft'
          java-version: '17'

      - name: Restore dependencies
        run: dotnet restore SacnController/SacnController.csproj

      - name: Decode keystore
        run: echo "${{ secrets.ANDROID_KEYSTORE_B64 }}" | base64 -d > ${{ github.workspace }}/keystore.jks

      - name: Publish signed APK
        run: |
          dotnet publish SacnController/SacnController.csproj \
            -f net8.0-android \
            -c Release \
            -p:AndroidKeyStore=true \
            -p:AndroidSigningKeyStore=${{ github.workspace }}/keystore.jks \
            -p:AndroidSigningKeyAlias=${{ secrets.ANDROID_KEY_ALIAS }} \
            -p:AndroidSigningKeyPass=${{ secrets.ANDROID_KEY_PASSWORD }} \
            -p:AndroidSigningStorePass=${{ secrets.ANDROID_KEYSTORE_PASSWORD }}

      - name: Find APK
        id: find_apk
        run: |
          APK_PATH=$(find . -name '*.apk' -path '*/publish/*' | head -1)
          echo "apk_path=$APK_PATH" >> $GITHUB_OUTPUT
          echo "apk_name=$(basename $APK_PATH)" >> $GITHUB_OUTPUT

      - name: Create GitHub Release
        uses: softprops/action-gh-release@v2
        with:
          files: ${{ steps.find_apk.outputs.apk_path }}
          generate_release_notes: true
        env:
          GITHUB_TOKEN: ${{ secrets.GITHUB_TOKEN }}
```

### Required Repository Secrets

| Secret | Description |
|---|---|
| `ANDROID_KEYSTORE_B64` | Base64-encoded `.jks` keystore file (`base64 -w0 keystore.jks`) |
| `ANDROID_KEY_ALIAS` | Key alias within the keystore |
| `ANDROID_KEY_PASSWORD` | Password for the key |
| `ANDROID_KEYSTORE_PASSWORD` | Password for the keystore |

### Keystore Generation (one-time)

```bash
keytool -genkeypair -v \
  -keystore sacn-controller.jks \
  -keyalg RSA -keysize 2048 -validity 10000 \
  -alias sacn-controller \
  -storepass <password> -keypass <password>

# Encode for the secret
base64 -w0 sacn-controller.jks | pbcopy
```

### Notes

- The workflow produces a signed release APK attached to a GitHub Release
- Release notes are auto-generated from commits since the previous tag
- The APK is not uploaded to Google Play — this is a sideload-only distribution for now
- If the app project path differs from `SacnController/`, update the path in the workflow accordingly

## Out of Scope (for now)

- Multiple universes or arbitrary channel mapping
- Fixture profiles / patching
- Scene saving / recall
- Discovery (receivers are pre-configured)
- iOS build target
- Settings screen

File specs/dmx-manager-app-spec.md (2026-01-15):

# DMX Bridge Manager Application Specification

## 1. Overview

### 1.1 Purpose
A cross-platform web application for managing fleets of ESP32 sACN-to-DMX bridge devices. The application enables technicians to discover, configure, monitor, debug, and update multiple devices from a single interface.

### 1.2 Target Users
- Lighting technicians deploying multiple DMX bridges in venues
- System integrators managing device fleets
- Developers debugging device firmware

### 1.3 Key Capabilities
- **Device Discovery**: Automatic mDNS-based discovery of all DMX bridges on the network
- **Batch Configuration**: Configure multiple devices simultaneously (universe, name, WiFi)
- **Fleet Status Monitoring**: Real-time dashboard showing health of all devices
- **Remote Firmware Updates**: OTA flash multiple devices in parallel
- **Debugging Tools**: Live device metrics, packet statistics, and log viewing

---

## 2. Architecture

### 2.1 Technology Stack

| Component | Technology | Rationale |
|---|---|---|
| Runtime | Node.js 20+ | Cross-platform, excellent network libraries |
| Framework | Electron or local web server | Native app feel with web technologies |
| Frontend | Vue 3 with TypeScript | Composition API, reactive, type-safe UI |
| Styling | Tailwind CSS | Rapid UI development, dark mode support |
| State | Pinia | Official Vue store, devtools integration |
| mDNS | bonjour-service (Node.js) | Cross-platform service discovery |
| HTTP Client | Axios or fetch | Device API communication |
| Build | Vite | First-class Vue support, fast HMR |

### 2.2 Deployment Options

**Option A: Electron Desktop App (Recommended)**
- Single executable for Windows, macOS, Linux
- Native mDNS access without browser restrictions
- File system access for firmware binaries
- Tray icon for background monitoring

**Option B: Local Web Server**
- Node.js backend with Express
- React frontend served locally
- Access via `http://localhost:3000`
- Requires Node.js installation

### 2.3 System Diagram

```
┌─────────────────────────────────────────────────────────────────┐
│                    DMX Bridge Manager App                        │
├─────────────────────────────────────────────────────────────────┤
│  ┌─────────────┐ ┌─────────────┐ ┌─────────────┐ ┌───────────┐ │
│  │  Discovery  │ │  Device API │ │  Firmware   │ │   WiFi    │ │
│  │  Service    │ │  Client     │ │  Uploader   │ │ Provision │ │
│  │  (mDNS)     │ │  (HTTP/JSON)│ │  (Multipart)│ │ (Native)  │ │
│  └──────┬──────┘ └──────┬──────┘ └──────┬──────┘ └─────┬─────┘ │
│         │               │               │              │        │
│         └───────────────┴───────────────┴──────────────┘        │
│                                │                                 │
│  ┌─────────────────────────────┴─────────────────────────────┐  │
│  │                     Vue UI Layer                         │  │
│  │  ┌──────────┐ ┌──────────┐ ┌──────────┐ ┌──────────────┐  │  │
│  │  │ Device   │ │ Config   │ │ Firmware │ │ Provisioning │  │  │
│  │  │ List     │ │ Panel    │ │ Manager  │ │ Wizard       │  │  │
│  │  └──────────┘ └──────────┘ └──────────┘ └──────────────┘  │  │
│  └───────────────────────────────────────────────────────────┘  │
└─────────────────────────────────────────────────────────────────┘
                                │
                    ┌───────────┴───────────┐
                    │   Local Network       │
                    │   (WiFi/Ethernet)     │
                    └───────────┬───────────┘
                                │
        ┌───────────────────────┼───────────────────────┐
        │                       │                       │
   ┌────┴────┐            ┌────┴────┐            ┌────┴────┐
   │ DMX     │            │ DMX     │            │ DMX     │
   │ Bridge  │            │ Bridge  │            │ Bridge  │
   │ Device 1│            │ Device 2│            │ Device N│
   └─────────┘            └─────────┘            └─────────┘
```

---

## 3. Features & Functional Requirements

### 3.1 Device Discovery

#### 3.1.1 Automatic Discovery (Network Mode)
- Continuously browse for `_sacn-dmx._tcp` mDNS services
- Parse TXT records for universe, MAC, and firmware version
- Resolve IP addresses and hostnames
- Display devices within 2 seconds of appearing on network

#### 3.1.2 AP Discovery & Provisioning
Discover and provision unconfigured devices that are broadcasting their own WiFi access points.

**AP Network Pattern**
- Default device AP SSID format: `DMX-Bridge-XXXX` (where XXXX is last 4 hex digits of MAC)
- Configurable pattern matching: `DMX-Bridge-*` (glob) or `DMX-Bridge-[A-F0-9]{4}` (regex)
- AP has no password by default
- Device IP in AP mode: `192.168.4.1`

**Discovery Process**
1. Scan for WiFi networks matching the configured pattern
2. Display list of discovered AP networks with signal strength
3. User selects which APs to provision (multi-select)
4. Application connects to each AP sequentially and retrieves device info

**Provisioning Workflow**
```
┌─────────────────────────────────────────────────────────────────┐
│                    AP Provisioning Wizard                        │
├─────────────────────────────────────────────────────────────────┤
│                                                                  │
│  Step 1: Scan for Device APs                                    │
│  ┌────────────────────────────────────────────────────────────┐ │
│  │  Pattern: [DMX-Bridge-*        ]  [Scan Networks]          │ │
│  └────────────────────────────────────────────────────────────┘ │
│                                                                  │
│  Found 3 device access points:                                  │
│  ┌────────────────────────────────────────────────────────────┐ │
│  │  ☑ DMX-Bridge-A1B2    -45 dBm  ████████░░  Excellent       │ │
│  │  ☑ DMX-Bridge-C3D4    -62 dBm  █████░░░░░  Good            │ │
│  │  ☑ DMX-Bridge-E5F6    -78 dBm  ██░░░░░░░░  Fair            │ │
│  └────────────────────────────────────────────────────────────┘ │
│                                                                  │
│  Step 2: Configure WiFi Credentials                             │
│  ┌────────────────────────────────────────────────────────────┐ │
│  │  Target Network SSID:     [VenueWiFi                    ]  │ │
│  │  Target Network Password: [••••••••••••                 ]  │ │
│  └────────────────────────────────────────────────────────────┘ │
│                                                                  │
│  Step 3: Device Configuration (Optional)                        │
│  ┌────────────────────────────────────────────────────────────┐ │
│  │  Device Name Template:    [Stage-{n}                    ]  │ │
│  │  sACN Universe:           [1         ]                     │ │
│  └────────────────────────────────────────────────────────────┘ │
│                                                                  │
│                              [Cancel]  [Provision 3 Devices]    │
└─────────────────────────────────────────────────────────────────┘
```

**Per-Device Provisioning Sequence**
For each selected device AP:
1. **Disconnect** from current WiFi network
2. **Connect** to device AP (e.g., `DMX-Bridge-A1B2`)
3. **Verify** connection by fetching `GET http://192.168.4.1/api/status`
4. **Configure** device via `POST http://192.168.4.1/api/config`:
   - WiFi SSID and password (required)
   - Device name (from template)
   - sACN universe (from sequence)
5. **Wait** for device to reboot and connect to target network
6. **Reconnect** to original/target network
7. **Verify** device appears on network via mDNS discovery
8. **Repeat** for next device

**Provisioning Progress UI**
```
┌─────────────────────────────────────────────────────────────────┐
│                    Provisioning Progress                         │
├─────────────────────────────────────────────────────────────────┤
│                                                                  │
│  Overall: ████████████░░░░░░░░  2/3 devices (67%)               │
│                                                                  │
│  ✓ DMX-Bridge-A1B2 → Stage-1                                    │
│    Connected to network, universe 1                             │
│                                                                  │
│  ● DMX-Bridge-C3D4 → Stage-2                          [Working] │
│    ├─ ✓ Connected to device AP                                  │
│    ├─ ✓ Retrieved device info                                   │
│    ├─ ✓ Sent configuration                                      │
│    ├─ ○ Waiting for device reboot...                            │
│    └─ ○ Verifying on target network                             │
│                                                                  │
│  ○ DMX-Bridge-E5F6 → Stage-3                          [Pending] │
│                                                                  │
│                                            [Cancel Remaining]    │
└─────────────────────────────────────────────────────────────────┘
```

**Platform Requirements**
- **Electron (Required)**: Native WiFi scanning and connection requires OS-level APIs
  - macOS: CoreWLAN framework via native Node addon
  - Windows: WlanAPI via native Node addon
  - Linux: NetworkManager D-Bus API or iwlist
- **Library**: `node-wifi` or custom native bindings
- **Permissions**: May require administrator/root privileges for WiFi control

**Error Handling**
| Error | Recovery |
|---|---|
| Cannot connect to device AP | Skip device, add to retry list |
| Device API unreachable at 192.168.4.1 | Retry connection, then skip |
| WiFi credentials rejected by target network | Abort provisioning, notify user |
| Device doesn't appear on target network | Wait longer (30s timeout), then mark as failed |
| Lost connection during provisioning | Attempt to reconnect and resume |

**Provisioning Templates**
Save and reuse provisioning configurations:
```typescript
interface ProvisioningTemplate {
  name: string;                    // Template name
  apPattern: string;               // AP SSID pattern (glob or regex)
  targetSsid: string;              // Target WiFi network
  targetPassword?: string;         // Optionally save password (encrypted)
  deviceNameTemplate: string;      // e.g., "Stage-{n}"
  sacnUniverse: number;            // Same universe for all devices
}
```

#### 3.1.3 Manual Discovery
- Add device by IP address or hostname
- Support for devices on different subnets (with known IP)
- Persist manually added devices between sessions

#### 3.1.4 Device List
- Show all discovered devices in sortable table
- Columns: Name, IP, Universe, Status, Signal, Firmware
- Visual indicators: Online (green), Offline (red), Updating (yellow)
- Filter by: Online/Offline, Universe, Firmware version
- Search by device name or IP

### 3.2 Batch Configuration

#### 3.2.1 Multi-Select
- Checkbox selection of multiple devices
- "Select All" / "Select None" / "Select Filtered"
- Selection persists across tab navigation

#### 3.2.2 Batch Settings Panel
When multiple devices selected, show configuration form:

| Setting | Input Type | Validation | Notes |
|---|---|---|---|
| Device Name | Text + template | 1-32 chars | Support `{n}` for sequential numbering |
| sACN Universe | Number | 1-63999 | Same universe applied to all selected devices |
| WiFi SSID | Text | 1-32 chars | Optional - only if changing networks |
| WiFi Password | Password | 8-63 chars | Required if SSID provided |

#### 3.2.3 Configuration Templates
- Sequential naming: `Stage-{n}` → Stage-1, Stage-2, Stage-3...
- Common universe: All devices receive the same sACN universe
- Preview changes before applying
- Save templates for reuse

#### 3.2.4 Batch Apply Process
1. Validate all settings client-side
2. Show confirmation dialog with affected devices
3. Apply to each device sequentially (configurable parallel limit)
4. Show progress bar and per-device status
5. Retry failed devices with exponential backoff
6. Generate summary report (success/failed counts)

### 3.3 Fleet Status Monitoring

#### 3.3.1 Dashboard View
Overview cards showing:
- Total devices discovered
- Online vs offline count
- Devices receiving sACN data
- Average WiFi signal strength
- Firmware version distribution (pie chart)

#### 3.3.2 Device Detail Panel
Click device to show expanded status:
```
┌─────────────────────────────────────────────────────────┐
│  DMX-Bridge-A1B2                              ● Online  │
├─────────────────────────────────────────────────────────┤
│  Network                                                │
│  ├─ IP: 192.168.1.50                                   │
│  ├─ SSID: VenueWiFi                                    │
│  ├─ Signal: -52 dBm (Good)                             │
│  └─ MAC: AA:BB:CC:DD:A1:B2                             │
│                                                         │
│  sACN Status                                           │
│  ├─ Universe: 1                                        │
│  ├─ Source: ETC Eos (192.168.1.10)                     │
│  ├─ Priority: 100                                       │
│  ├─ Packets: 1,234,567 received                        │
│  ├─ Errors: 12 (0.001%)                                │
│  └─ Last Packet: 15ms ago                              │
│                                                         │
│  System                                                 │
│  ├─ Firmware: 1.0.0                                    │
│  ├─ Uptime: 3h 24m 15s                                 │
│  ├─ Free Heap: 180KB / 350KB                           │
│  ├─ Reboots: 3                                         │
│  └─ Last Reset: Power cycle                            │
└─────────────────────────────────────────────────────────┘
```

#### 3.3.3 Auto-Refresh
- Poll device status every 5 seconds (configurable)
- Efficient: only poll visible/selected devices
- Show "last updated" timestamp
- Manual refresh button

#### 3.3.4 Alerts & Notifications
- Device goes offline → Desktop notification
- High packet error rate (>1%) → Warning indicator
- Low WiFi signal (<-75 dBm) → Warning indicator
- Memory low (<50KB free) → Warning indicator

### 3.4 Remote Firmware Updates

#### 3.4.1 Firmware Management
- Select `.bin` firmware file from local filesystem
- Display firmware file info (size, hash)
- Store recently used firmware files
- Validate firmware file format before upload

#### 3.4.2 Batch OTA Update
1. Select target devices (filter by current version)
2. Choose firmware file
3. Confirm update (show current vs new version)
4. Upload to devices (configurable parallelism: 1-5 concurrent)
5. Progress tracking per device:
   - Uploading (0-100%)
   - Verifying
   - Rebooting
   - Confirming new version
6. Automatic rollback detection if device fails to come online

#### 3.4.3 Update Queue
- Queue updates for offline devices
- Retry when device comes online
- Timeout after configurable period (default: 1 hour)

#### 3.4.4 Rollback Support
- Show if rollback partition available per device
- Batch rollback to previous firmware
- Confirm before rollback

### 3.5 Debugging Tools

#### 3.5.1 Live Metrics View
Real-time charts (last 60 seconds):
- sACN packets per second
- WiFi RSSI over time
- Free heap memory
- DMX output FPS

#### 3.5.2 Packet Statistics
- Total packets received
- Error count and rate
- Source IP and name
- Priority level
- Packet rate (Hz)

#### 3.5.3 Device Actions
| Action | Description |
|---|---|
| Reboot | Restart device immediately |
| Factory Reset | Clear all settings (requires confirmation) |
| Identify | Flash LED pattern to physically locate device |
| Export Config | Download device configuration as JSON |
| Import Config | Upload configuration JSON to device |

#### 3.5.4 Batch Diagnostics
- Export fleet status report (CSV/JSON)
- Batch reboot selected devices
- Connectivity test (ping all devices)

---

## 4. User Interface Design

### 4.1 Layout Structure

```
┌─────────────────────────────────────────────────────────────────┐
│  ┌─────┐  DMX Bridge Manager              [Settings] [?]       │
│  │ ≡   │                                                        │
├──┴─────┴────────────────────────────────────────────────────────┤
│                                                                  │
│  ┌──────────────────────────────────────────────────────────┐   │
│  │  [🔍 Search...]           [Filter ▼]  [↻ Refresh]        │   │
│  └──────────────────────────────────────────────────────────┘   │
│                                                                  │
│  ┌─────────────────────────────────┬────────────────────────┐   │
│  │                                 │                         │   │
│  │      Device List                │    Detail Panel         │   │
│  │      (Master View)              │    (Selected Device)    │   │
│  │                                 │                         │   │
│  │  ☑ DMX-Stage-1    192.168.1.50 │    Status, Config,      │   │
│  │  ☑ DMX-Stage-2    192.168.1.51 │    Firmware, Debug      │   │
│  │  ☐ DMX-Stage-3    192.168.1.52 │    tabs                 │   │
│  │  ☐ DMX-Balcony    192.168.1.53 │                         │   │
│  │                                 │                         │   │
│  └─────────────────────────────────┴────────────────────────┘   │
│                                                                  │
│  ┌──────────────────────────────────────────────────────────┐   │
│  │  [Configure Selected (2)]  [Update Firmware]  [Reboot]   │   │
│  └──────────────────────────────────────────────────────────┘   │
│                                                                  │
└─────────────────────────────────────────────────────────────────┘
```

### 4.2 Views / Tabs

1. **Devices** (default) - List and manage all devices
2. **Provision** - AP discovery and device provisioning wizard
3. **Dashboard** - Fleet overview with statistics
4. **Firmware** - Manage firmware files and updates
5. **Settings** - Application preferences

### 4.3 Theme
- Dark mode by default (lighting technicians work in dark environments)
- Light mode option
- High contrast status indicators
- Accessible color palette (colorblind-friendly)

### 4.4 Responsive Design
- Minimum width: 1024px
- Collapsible side panels
- Mobile-friendly for tablet use on-site

---

## 5. API Integration

### 5.1 Device API Client

```typescript
interface DeviceClient {
  // Discovery
  discoverDevices(): AsyncGenerator<Device>;

  // Status
  getStatus(device: Device): Promise<DeviceStatus>;
  getConfig(device: Device): Promise<DeviceConfig>;

  // Configuration
  setConfig(device: Device, config: Partial<DeviceConfig>): Promise<void>;
  batchSetConfig(devices: Device[], configs: Partial<DeviceConfig>[]): Promise<BatchResult>;

  // Firmware
  getFirmwareInfo(device: Device): Promise<FirmwareInfo>;
  uploadFirmware(device: Device, firmware: Buffer, onProgress: (p: number) => void): Promise<void>;
  rollbackFirmware(device: Device): Promise<void>;

  // Actions
  reboot(device: Device): Promise<void>;
  factoryReset(device: Device): Promise<void>;
}

interface ProvisioningService {
  // WiFi Network Scanning
  scanWifiNetworks(): Promise<WifiNetwork[]>;
  filterByPattern(networks: WifiNetwork[], pattern: string): WifiNetwork[];

  // WiFi Connection Management
  getCurrentNetwork(): Promise<string | null>;
  connectToNetwork(ssid: string, password?: string): Promise<void>;
  disconnectFromNetwork(): Promise<void>;

  // Provisioning Operations
  provisionDevice(
    apSsid: string,
    config: ProvisioningConfig,
    onProgress: (step: ProvisioningStep) => void
  ): Promise<ProvisioningResult>;

  batchProvision(
    apSsids: string[],
    config: BatchProvisioningConfig,
    onProgress: (deviceIndex: number, step: ProvisioningStep) => void
  ): Promise<BatchProvisioningResult>;

  // Template Management
  saveTemplate(template: ProvisioningTemplate): Promise<void>;
  getTemplates(): Promise<ProvisioningTemplate[]>;
  deleteTemplate(name: string): Promise<void>;
}
```

### 5.2 Device Endpoints Used

| Endpoint | Method | Purpose |
|---|---|---|
| `/api/status` | GET | Fetch device status and metrics |
| `/api/config` | GET | Fetch current configuration |
| `/api/config` | POST | Update configuration |
| `/api/reboot` | POST | Restart device |
| `/api/firmware` | GET | Get firmware status |
| `/api/firmware` | POST | Upload new firmware |
| `/api/firmware/rollback` | POST | Revert to previous firmware |

### 5.3 Error Handling

| Error Type | Handling |
|---|---|
| Network timeout | Retry with backoff, mark device as unreachable |
| 400 Bad Request | Display validation error to user |
| 404 Not Found | Device may have old firmware, show warning |
| 500 Server Error | Log error, suggest device reboot |
| Device offline | Queue operation, retry when online |

---

## 6. Data Models

### 6.1 Device

```typescript
interface Device {
  id: string;              // MAC address (unique identifier)
  name: string;            // Device name
  hostname: string;        // mDNS hostname
  ip: string;              // IP address
  port: number;            // HTTP port (80)
  mac: string;             // MAC address
  firmwareVersion: string; // Current firmware version
  universe: number;        // sACN universe
  discoveredAt: Date;      // When first discovered
  lastSeen: Date;          // Last successful communication
  isOnline: boolean;       // Current connectivity status
  isManual: boolean;       // Manually added vs discovered
}
```

### 6.2 DeviceStatus

```typescript
interface DeviceStatus {
  // WiFi
  wifiConnected: boolean;
  wifiSsid: string;
  wifiRssi: number;
  wifiSignalQuality: 'excellent' | 'good' | 'fair' | 'poor';
  ipAddress: string;

  // sACN
  sacnUniverse: number;
  sacnPacketsReceived: number;
  sacnPacketErrors: number;
  sacnSourceIp: string | null;
  sacnSourceName: string | null;
  sacnPriority: number;
  lastPacketMsAgo: number;

  // DMX
  dmxFps: number;

  // System
  firmwareVersion: string;
  uptimeSeconds: number;
  freeHeapBytes: number;
  minFreeHeapBytes: number;
  rebootCount: number;
  lastRebootReason: string;
}
```

### 6.3 DeviceConfig

```typescript
interface DeviceConfig {
  deviceName: string;
  sacnUniverse: number;
  wifiSsid?: string;
  wifiPassword?: string;
}
```

### 6.4 BatchOperation

```typescript
interface BatchOperation {
  id: string;
  type: 'config' | 'firmware' | 'reboot';
  devices: Device[];
  status: 'pending' | 'running' | 'completed' | 'failed';
  progress: number;        // 0-100
  results: BatchResult[];
  startedAt: Date;
  completedAt?: Date;
}

interface BatchResult {
  device: Device;
  success: boolean;
  error?: string;
  duration: number;        // milliseconds
}
```

### 6.5 Provisioning Models

```typescript
interface WifiNetwork {
  ssid: string;
  bssid: string;           // MAC address of AP
  signalStrength: number;  // dBm
  signalQuality: 'excellent' | 'good' | 'fair' | 'poor';
  security: 'open' | 'wep' | 'wpa' | 'wpa2' | 'wpa3';
  channel: number;
  frequency: number;       // MHz (2.4GHz or 5GHz)
}

interface ProvisioningTemplate {
  id: string;
  name: string;                    // User-friendly template name
  apPattern: string;               // SSID pattern (glob or regex)
  apPatternType: 'glob' | 'regex';
  targetSsid: string;              // Target WiFi network SSID
  targetPassword?: string;         // Encrypted password (optional storage)
  deviceNameTemplate: string;      // e.g., "Stage-{n}", "DMX-{mac4}"
  sacnUniverse: number;            // Same universe for all devices
  createdAt: Date;
  updatedAt: Date;
}

interface ProvisioningConfig {
  targetSsid: string;
  targetPassword: string;
  deviceName?: string;
  sacnUniverse?: number;
}

interface BatchProvisioningConfig {
  targetSsid: string;
  targetPassword: string;
  deviceNameTemplate: string;      // Supports {n}, {mac4}, {mac6}
  startingNumber: number;          // For {n} placeholder
  sacnUniverse: number;            // Same universe for all devices
}

type ProvisioningStep =
  | { type: 'disconnecting' }
  | { type: 'connecting_to_ap'; ssid: string }
  | { type: 'connected_to_ap' }
  | { type: 'fetching_device_info' }
  | { type: 'device_info_received'; mac: string; firmware: string }
  | { type: 'sending_config' }
  | { type: 'config_sent' }
  | { type: 'waiting_for_reboot'; timeoutMs: number }
  | { type: 'reconnecting_to_network'; ssid: string }
  | { type: 'verifying_device_online'; timeoutMs: number }
  | { type: 'device_online'; ip: string }
  | { type: 'completed' }
  | { type: 'failed'; error: string };

interface ProvisioningResult {
  success: boolean;
  apSsid: string;
  device?: Device;         // Populated if successful
  assignedName?: string;
  assignedUniverse?: number;
  error?: string;
  duration: number;        // Total time in ms
}

interface BatchProvisioningResult {
  total: number;
  successful: number;
  failed: number;
  results: ProvisioningResult[];
  duration: number;        // Total batch time in ms
}

interface ProvisioningSession {
  id: string;
  status: 'scanning' | 'configuring' | 'provisioning' | 'completed' | 'cancelled';
  template?: ProvisioningTemplate;
  discoveredAPs: WifiNetwork[];
  selectedAPs: string[];   // SSIDs selected for provisioning
  config: BatchProvisioningConfig;
  currentDeviceIndex: number;
  results: ProvisioningResult[];
  startedAt: Date;
  completedAt?: Date;
}
```

---

## 7. Non-Functional Requirements

### 7.1 Performance
- Device discovery latency: <2 seconds
- Status refresh: <500ms per device
- UI responsiveness: <100ms for interactions
- Support 100+ devices without degradation

### 7.2 Reliability
- Graceful handling of network failures
- No data loss on application crash
- Automatic reconnection to devices

### 7.3 Security
- No sensitive data transmitted to external servers
- WiFi passwords not stored in application (only sent to devices)
- HTTPS support for devices (future enhancement)

### 7.4 Compatibility
- **Operating Systems**: Windows 10+, macOS 11+, Linux (Ubuntu 20.04+)
- **Node.js**: 20 LTS or later
- **Browsers** (if web mode): Chrome 100+, Firefox 100+, Safari 15+

---

## 8. Configuration & Persistence

### 8.1 Application Settings

```typescript
interface AppSettings {
  // Discovery
  discoveryEnabled: boolean;
  discoveryInterval: number;     // ms between scans

  // Status
  statusPollInterval: number;    // ms between status refreshes
  pollOnlyVisible: boolean;      // Optimize for large fleets

  // Updates
  maxConcurrentUpdates: number;  // Parallel firmware uploads
  updateRetryCount: number;
  updateRetryDelay: number;      // ms

  // Provisioning
  defaultApPattern: string;      // Default SSID pattern (e.g., "DMX-Bridge-*")
  apPatternType: 'glob' | 'regex';
  provisioningTimeout: number;   // ms to wait for device to join network
  provisioningRetryCount: number;
  saveProvisioningPasswords: boolean;  // Store WiFi passwords (encrypted)

  // UI
  theme: 'dark' | 'light' | 'system';
  showOfflineDevices: boolean;
  confirmDestructiveActions: boolean;

  // Notifications
  notifyDeviceOffline: boolean;
  notifyUpdateComplete: boolean;
  notifyProvisioningComplete: boolean;
}
```

### 8.2 Persistent Storage
- **Electron**: electron-store (JSON file in app data)
- **Web**: localStorage + IndexedDB for larger data

### 8.3 Stored Data
- Application settings
- Manually added devices
- Recent firmware files
- Configuration templates
- Window size/position

---

## 9. Implementation Phases

### Phase 1: Core Functionality
- [ ] Project setup (Vite + Vue 3 + TypeScript + Electron)
- [ ] mDNS discovery service
- [ ] Device list UI with status indicators
- [ ] Single device status view
- [ ] Single device configuration
- [ ] Manual device addition

### Phase 2: AP Provisioning
- [ ] Native WiFi module setup (platform-specific bindings)
- [ ] WiFi network scanning with pattern matching
- [ ] AP list UI with signal strength indicators
- [ ] Provisioning wizard flow (3-step form)
- [ ] Sequential device provisioning with progress tracking
- [ ] Provisioning template save/load
- [ ] Error handling and retry for failed provisions

### Phase 3: Batch Operations
- [ ] Multi-device selection
- [ ] Batch configuration UI
- [ ] Configuration templates
- [ ] Batch apply with progress tracking
- [ ] Error handling and retry logic

### Phase 4: Firmware Management
- [ ] Firmware file selection
- [ ] Single device OTA update
- [ ] Batch firmware updates
- [ ] Progress tracking per device
- [ ] Rollback support

### Phase 5: Advanced Features
- [ ] Dashboard with fleet statistics
- [ ] Live metrics charts
- [ ] Desktop notifications
- [ ] Export/import configurations
- [ ] Fleet diagnostics report

### Phase 6: Polish
- [ ] Dark/light theme toggle
- [ ] Keyboard shortcuts
- [ ] Comprehensive error messages
- [ ] Help documentation
- [ ] Performance optimization

---

## 10. File Structure

```
dmx-manager/
├── package.json
├── vite.config.ts
├── tsconfig.json
├── electron/                    # Electron main process
│   ├── main.ts
│   ├── preload.ts
│   ├── discovery.ts             # mDNS service
│   └── wifi/                    # Native WiFi control
│       ├── index.ts             # Platform detection & routing
│       ├── macos.ts             # CoreWLAN bindings
│       ├── windows.ts           # WlanAPI bindings
│       └── linux.ts             # NetworkManager D-Bus
├── src/
│   ├── main.ts                  # Vue entry point
│   ├── App.vue
│   ├── api/
│   │   ├── client.ts            # HTTP client for device API
│   │   ├── discovery.ts         # mDNS discovery (renderer)
│   │   ├── provisioning.ts      # Provisioning service
│   │   └── types.ts             # API response types
│   ├── components/
│   │   ├── DeviceList/
│   │   │   ├── DeviceList.vue
│   │   │   └── DeviceRow.vue
│   │   ├── DeviceDetail/
│   │   │   └── DeviceDetail.vue
│   │   ├── ConfigPanel/
│   │   │   └── ConfigPanel.vue
│   │   ├── FirmwareManager/
│   │   │   └── FirmwareManager.vue
│   │   ├── Dashboard/
│   │   │   └── Dashboard.vue
│   │   ├── Provisioning/        # AP provisioning wizard
│   │   │   ├── ProvisioningWizard.vue
│   │   │   ├── APScanner.vue    # WiFi network scanner
│   │   │   ├── APList.vue       # Discovered AP list
│   │   │   ├── ConfigForm.vue   # WiFi + device config form
│   │   │   ├── ProgressView.vue # Provisioning progress
│   │   │   └── TemplateManager.vue
│   │   └── common/
│   │       ├── BaseButton.vue
│   │       ├── BaseInput.vue
│   │       └── StatusIndicator.vue
│   ├── composables/             # Vue composables (like React hooks)
│   │   ├── useDevices.ts
│   │   ├── useDeviceStatus.ts
│   │   ├── useBatchOperation.ts
│   │   ├── useWifiNetworks.ts   # WiFi scanning composable
│   │   └── useProvisioning.ts   # Provisioning workflow composable
│   ├── stores/                  # Pinia stores
│   │   ├── devices.ts
│   │   ├── settings.ts
│   │   ├── operations.ts
│   │   └── provisioning.ts      # Provisioning state
│   ├── utils/
│   │   ├── formatting.ts
│   │   ├── validation.ts
│   │   └── ssidPattern.ts       # Glob/regex matching for SSIDs
│   ├── views/                   # Page-level components
│   │   ├── DevicesView.vue
│   │   ├── ProvisionView.vue
│   │   ├── DashboardView.vue
│   │   ├── FirmwareView.vue
│   │   └── SettingsView.vue
│   ├── router/
│   │   └── index.ts             # Vue Router configuration
│   └── styles/
│       └── globals.css
├── public/
│   └── icons/
└── dist/                        # Build output
```

---

## 11. Future Enhancements

The following features are out of scope for initial release but may be considered for future versions:

- **Device Groups**: Organize devices into logical groups (e.g., "Stage Left", "House")
- **Scheduling**: Schedule configuration changes or reboots
- **Audit Log**: Track all configuration changes with timestamps
- **Multi-User**: Support for multiple users with role-based permissions
- **Cloud Sync**: Optional sync of device registry across installations
- **Firmware Repository**: Automatic firmware version checking and downloads
- **DMX Monitor**: View live DMX channel values per device
- **Network Topology**: Visual map of device locations
- **API for Automation**: REST API for scripting and CI/CD integration
- **Localization**: Multi-language support

---

## 12. Appendix

### A. Device API Reference

See [sacn-dmx-spec.md](sacn-dmx-spec.md) for complete device API documentation.

### B. mDNS Service Format

```
Service: _sacn-dmx._tcp.local
Port: 80
TXT Records:
  - universe=<1-63999>
  - mac=<AA:BB:CC:DD:EE:FF>
  - version=<firmware_version>
```

### C. Keyboard Shortcuts

| Shortcut | Action |
|---|---|
| `Ctrl/Cmd + R` | Refresh device list |
| `Ctrl/Cmd + A` | Select all devices |
| `Ctrl/Cmd + D` | Deselect all devices |
| `Ctrl/Cmd + F` | Focus search box |
| `Ctrl/Cmd + P` | Open provisioning wizard |
| `Ctrl/Cmd + Shift + S` | Scan for device APs |
| `Ctrl/Cmd + ,` | Open settings |
| `Delete` | Remove selected manual device |
| `Enter` | Open device detail panel |
| `Escape` | Close dialogs/panels |

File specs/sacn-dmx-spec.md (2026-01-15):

# sACN to DMX Bridge — Technical Specification

## Overview

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

## Hardware Platform

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

## Functional Requirements

### F1: WiFi Connectivity

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

### F1A: Serial Configuration Interface

A serial interface for bulk provisioning during manufacturing or deployment.

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

**Serial command format:**
```
CONFIG:{"wifi_ssid":"NetworkName","wifi_password":"password123","sacn_universe":1,"device_name":"Stage-Left"}
```

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

**Success response:**
```
OK:{"message":"Configuration saved","reboot_required":true}
```

**Error response:**
```
ERROR:{"message":"Invalid JSON format"}
```

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

**Example provisioning session:**
```
> STATUS
< OK:{"device_name":"DMX-Bridge-A1B2","wifi_connected":false,"sacn_universe":1,...}
> CONFIG:{"wifi_ssid":"VenueWiFi","wifi_password":"secret","sacn_universe":5}
< OK:{"message":"Configuration saved","reboot_required":true}
< REBOOTING...
```

### F1B: SmartConfig Provisioning

Support for Espressif SmartConfig (ESP-Touch) protocol for bulk WiFi provisioning.

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

### F2: sACN Reception

The device shall use the ESPAsyncE131 library (https://github.com/forkineye/ESPAsyncE131) for sACN packet handling.

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

### F3: DMX Output

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

### F3A: mDNS Discovery

The device shall advertise itself via mDNS (Bonjour/Avahi) for easy discovery on the network.

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

**Example mDNS advertisement:**
```
Service: _sacn-dmx._tcp.local
Host: dmx-bridge-a1b2.local
Port: 80
TXT: universe=1, mac=AA:BB:CC:DD:A1:B2, version=1.0.0
```

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

**Discovery commands:**

On macOS/Linux:
```bash
dns-sd -B _sacn-dmx._tcp local
# or
avahi-browse -rt _sacn-dmx._tcp
```

On Windows (with Bonjour installed):
```bash
dns-sd -B _sacn-dmx._tcp local
```

**Programmatic discovery (Python example):**
```python
from zeroconf import ServiceBrowser, Zeroconf

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

zeroconf = Zeroconf()
browser = ServiceBrowser(zeroconf, "_sacn-dmx._tcp.local.", Listener())
```

### F4: Configuration Persistence

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

### F5: JSON API

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

#### F5.1: GET /api/status

Returns current device status including diagnostic information.

**Response:**
```json
{
  "device_name": "DMX-Bridge-A1B2",
  "firmware_version": "1.0.0",
  "wifi_connected": true,
  "wifi_ssid": "LightingNetwork",
  "wifi_rssi": -52,
  "wifi_signal_quality": "good",
  "ip_address": "192.168.1.50",
  "mac_address": "AA:BB:CC:DD:A1:B2",
  "sacn_universe": 1,
  "sacn_packets_received": 123456,
  "sacn_packets_errors": 12,
  "sacn_source_ip": "192.168.1.10",
  "sacn_source_name": "ETC Eos",
  "sacn_priority": 100,
  "last_packet_ms_ago": 12,
  "dmx_fps": 40,
  "uptime_seconds": 3600,
  "free_heap_bytes": 180000,
  "min_free_heap_bytes": 165000,
  "cpu_temperature_c": 42.5,
  "reboot_count": 3,
  "last_reboot_reason": "power_on"
}
```

**Field descriptions:**

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

#### F5.2: GET /api/config

Returns current configuration.

**Response:**
```json
{
  "device_name": "DMX-Bridge-A1B2",
  "sacn_universe": 1,
  "wifi_ssid": "LightingNetwork"
}
```

Note: WiFi password shall never be returned by the API.

#### F5.3: POST /api/config

Batch update configuration settings.

**Request body (all fields optional):**
```json
{
  "device_name": "Stage-Left-DMX",
  "sacn_universe": 2,
  "wifi_ssid": "NewNetwork",
  "wifi_password": "newpassword123"
}
```

**Response:**
```json
{
  "success": true,
  "message": "Configuration updated. Reboot required for WiFi changes.",
  "reboot_required": true
}
```

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

#### F5.4: POST /api/reboot

Triggers a device restart.

**Request body:** None required.

**Response:**
```json
{
  "success": true,
  "message": "Rebooting in 1 second."
}
```

The device shall delay 1 second before rebooting to allow the HTTP response to complete.

#### F5.5: POST /api/identify

Triggers visual identification of the device using the status LED.

**Request body (optional):**
```json
{
  "duration": 10
}
```

| Field | Type | Default | Range | Description |
|---|---|---|---|---|
| `duration` | integer | 5 | 1–30 | Identification duration in seconds |

**Response:**
```json
{
  "success": true,
  "message": "Identifying device",
  "duration_seconds": 10
}
```

**LED behaviour during identification:**
- LED flashes alternating white and magenta at 5Hz (200ms per colour)
- After the specified duration, LED returns to normal state (off during normal operation)

**Use case:** When multiple devices are installed, this endpoint allows an operator to visually identify a specific device by its IP address or hostname without physically accessing it.

**Example using curl:**
```bash
# Default 5 second identification
curl -X POST http://dmx-bridge-a1b2.local/api/identify

# Custom 10 second identification
curl -X POST -H "Content-Type: application/json" -d '{"duration":10}' http://dmx-bridge-a1b2.local/api/identify
```

#### F5.7: POST /api/firmware

Upload new firmware binary to update the device.

**Request:**
- Content-Type: `multipart/form-data`
- Field name: `firmware`
- File: compiled firmware binary (.bin file)

**Example using curl:**
```bash
curl -X POST -F "firmware=@firmware_v1.1.0.bin" http://dmx-bridge-a1b2.local/api/firmware
```

**Response (success):**
```json
{
  "success": true,
  "message": "Firmware uploaded successfully. Validating...",
  "new_version": "1.1.0",
  "previous_version": "1.0.0",
  "rebooting": true
}
```

**Response (validation failed):**
```json
{
  "success": false,
  "error": "Firmware validation failed: invalid magic bytes"
}
```

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

#### F5.8: POST /api/firmware/rollback

Manually trigger a rollback to the previous firmware version.

**Request body:** None required.

**Response (success):**
```json
{
  "success": true,
  "message": "Rolling back to previous firmware",
  "current_version": "1.1.0",
  "rollback_version": "1.0.0",
  "rebooting": true
}
```

**Response (no rollback available):**
```json
{
  "success": false,
  "error": "No previous firmware available for rollback"
}
```

#### F5.9: GET /api/firmware

Returns current firmware information and rollback status.

**Response:**
```json
{
  "current_version": "1.1.0",
  "previous_version": "1.0.0",
  "rollback_available": true,
  "last_update": "2024-01-15T14:32:00Z",
  "update_confirmed": true,
  "partition_scheme": "ota_0 (active), ota_1 (previous)"
}
```

#### F5.10: API Error Handling

All error responses shall use appropriate HTTP status codes and include a JSON body:

```json
{
  "success": false,
  "error": "Invalid universe number. Must be 1-63999."
}
```

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

### F6: Status LED Behaviour

The WS2812 LED on GPIO 8 shall indicate device state as follows:

| State | LED Behaviour |
|---|---|
| AP mode active | Pulsing blue (1 second cycle) |
| Connecting to WiFi | Pulsing yellow (0.5 second cycle) |
| Connected, awaiting first sACN packet | Solid green for 2 seconds, then off |
| Receiving sACN normally | Off |
| WiFi connection lost | Solid red until reconnected or AP mode entered |
| Error (unrecoverable) | Fast flashing red (4Hz) |
| Identify mode (via API) | Alternating white/magenta (5Hz) for configured duration |

**Rationale:** In normal installed operation, the LED remains off to avoid unwanted light pollution in performance environments. The identify mode uses distinctive white/magenta flashing to stand out from other status indicators.

### F7: Captive Portal Web Interface

The captive portal served in AP mode shall provide a minimal, functional HTML form.

#### F7.1: Page Structure

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

#### F7.2: Behaviour

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

#### F7.3: Styling

- Simple, functional appearance suitable for mobile browsers.
- No external CSS or JavaScript dependencies (fully self-contained).

## Non-Functional Requirements

### NF1: Performance

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

### NF2: Reliability

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

### NF3: Memory

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

## Software Architecture

### Recommended Task Structure

The application should use FreeRTOS tasks (available via Arduino ESP32 core):

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

### Shared Data

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

### Recommended Libraries

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

## Pin Assignment Summary

| GPIO | Function |
|---|---|
| 0 | DMX output (TX to MAX485 DI pin) |
| 8 | WS2812 status LED data |

## Configuration Defaults

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

## Testing Criteria

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

### TC4: JSON API
- [ ] GET /api/status returns correct information.
- [ ] GET /api/config returns current settings.
- [ ] POST /api/config updates settings correctly.
- [ ] POST /api/reboot triggers restart.
- [ ] POST /api/identify triggers LED identification with default duration.
- [ ] POST /api/identify with custom duration respects the specified time.
- [ ] Invalid requests return appropriate errors.

### TC5: Status LED
- [ ] LED pulses blue in AP mode.
- [ ] LED pulses yellow while connecting.
- [ ] LED shows green briefly on connection, then turns off.
- [ ] LED remains off during normal operation.
- [ ] LED shows red on connection loss.
- [ ] LED flashes white/magenta during identify mode and returns to normal after duration.

## Future Considerations (Out of Scope)

The following features are not included in this specification but may be considered for future versions:

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

---

*Specification version: 1.0*
*Target platform: ESP32-C6 with Arduino framework*

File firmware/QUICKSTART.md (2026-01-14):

# Quick Start Guide

Get your sACN to DMX Bridge up and running in 5 minutes!

## 1. Hardware Setup

Connect your ESP32-C6:

```
ESP32-C6          MAX485
GPIO 0    ───────> DI (Data In)
GND       ───────> GND

MAX485            DMX Connector
A         ───────> Pin 3 (Data+)
B         ───────> Pin 2 (Data-)
GND       ───────> Pin 1 (Ground)

Optional:
GPIO 8    ───────> WS2812 LED Data In
```

## 2. Software Setup

### Option A: Arduino IDE (Easiest)

1. **Install Arduino IDE 2.x** from https://www.arduino.cc/en/software

2. **Add ESP32 Boards**:
   - Open Preferences (Ctrl+Comma)
   - Add to "Additional Board Manager URLs":
     ```
     https://espressif.github.io/arduino-esp32/package_esp32_index.json
     ```
   - Open Board Manager (left sidebar)
   - Search "esp32" and install

3. **Install Libraries**:
   - Open Library Manager (left sidebar)
   - Install these libraries:
     - `ArduinoJson` by Benoit Blanchon
     - `FastLED` by Daniel Garcia
   - **Install sACN library** (not in library manager):
     - Download ZIP from https://github.com/sstaub/sACN
     - Go to **Sketch → Include Library → Add .ZIP Library**
     - Select the downloaded ZIP file

4. **Configure Board**:
   - Select **Tools → Board → ESP32 Arduino → ESP32C6 Dev Module**
   - Select **Tools → Partition Scheme → Minimal SPIFFS**
   - Select **Tools → USB CDC On Boot → Enabled**

5. **Upload**:
   - Open `DMX_Receiver.ino`
   - Connect ESP32-C6 via USB
   - Select correct port under **Tools → Port**
   - Click Upload (→) button

### Option B: PlatformIO (For Advanced Users)

1. Install VSCode + PlatformIO extension
2. Open this folder in VSCode
3. PlatformIO will auto-install dependencies
4. Click "Upload" in PlatformIO toolbar

## 3. First Configuration

### Via Captive Portal (Recommended)

1. **Power on device** (LED will pulse blue)

2. **Connect to WiFi network**:
   - Network name: `DMX-Bridge-XXXX`
   - No password

3. **Configure** (should auto-open, or go to `192.168.4.1`):
   - Enter your WiFi network name
   - Enter WiFi password
   - Set sACN universe (usually 1)
   - Click "Save & Connect"

4. **Done!** Device reboots and connects to your network

### Via Serial (For Testing)

1. Open Serial Monitor (115200 baud)
2. Send:
   ```
   CONFIG:{"wifi_ssid":"MyNetwork","wifi_password":"mypass123","sacn_universe":1}
   ```
3. Device saves and reboots

## 4. Test It

### Check Connection

Open Serial Monitor (115200 baud), you should see:
```
=================================
sACN to DMX Bridge
Firmware: v1.0.0
=================================

[WiFi] Connected!
  IP: 192.168.1.123
  RSSI: -45 dBm
[sACN] Listening on universe 1
[HTTP] Server started on port 80
```

### Check Status via API

```bash
# Replace with your device's IP or hostname
curl http://192.168.1.123/api/status

# Or use mDNS:
curl http://dmx-bridge-xxxx.local/api/status
```

### Send sACN Data

Use any sACN lighting software:

- **QLC+** (Free, Open Source)
  - Download from https://www.qlcplus.org/
  - Configure output: E1.31 (sACN) on universe 1
  - Create a simple scene and watch DMX output!

- **ETC Eos** (Professional)
- **GrandMA** (Professional)
- **Chamsys MagicQ** (Free version available)

## 5. Verify DMX Output

1. **With DMX Tester**: Connect to output, should see data

2. **With Fixture**: Connect a DMX light
   - Most fixtures default to DMX address 1
   - In your software, set channel 1-3 (typically RGB)
   - Light should respond!

3. **With Multimeter**:
   - Measure voltage between A and B
   - Should see ~2-5V differential when data is transmitting

## Troubleshooting

| Problem | Solution |
|---|---|
| Can't see WiFi network | Wait 30 seconds after power-on for AP mode |
| Won't connect to WiFi | Check password, ensure 2.4GHz network |
| No DMX output | Check MAX485 wiring, verify connections |
| Can't access web interface | Try IP address instead of hostname |
| LED solid red | WiFi connection lost, device will retry |

## What's Next?

- **Configure Multiple Devices**: Use SmartConfig for bulk setup
- **Monitor Performance**: Check `/api/status` for packet counts
- **Update Firmware**: Use `/api/firmware` endpoint for OTA updates
- **Set Device Names**: Use `/api/config` to name each device

## Need Help?

1. Check full documentation in `README.md`
2. Review detailed spec in `sacn-dmx-spec.md`
3. Open Serial Monitor for debug messages
4. Check `/api/status` for system diagnostics

## Common sACN Software Setup

### QLC+ Configuration

1. **Inputs/Outputs** tab
2. Add output: **E1.31 (sACN)**
3. Set Universe: **1** (or your configured universe)
4. Set Multicast: **Enabled**
5. IP: Leave as multicast (239.255.0.1 for universe 1)
6. Click **OK**

### Lighting Console Setup

Most consoles:
1. Network settings → Add E1.31 output
2. Set universe number (must match device)
3. Use multicast mode (not unicast)
4. Start sending data!

---

**Congratulations! Your sACN to DMX Bridge is ready!** 🎭✨

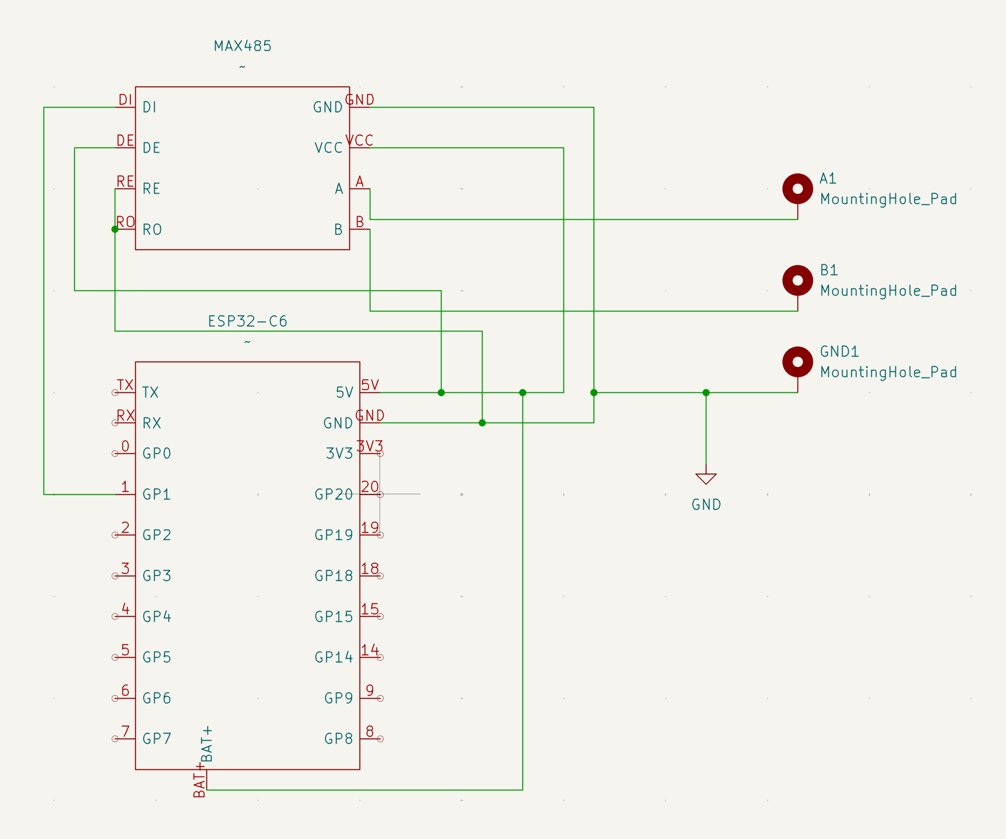
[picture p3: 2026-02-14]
docs/images/schematic.png

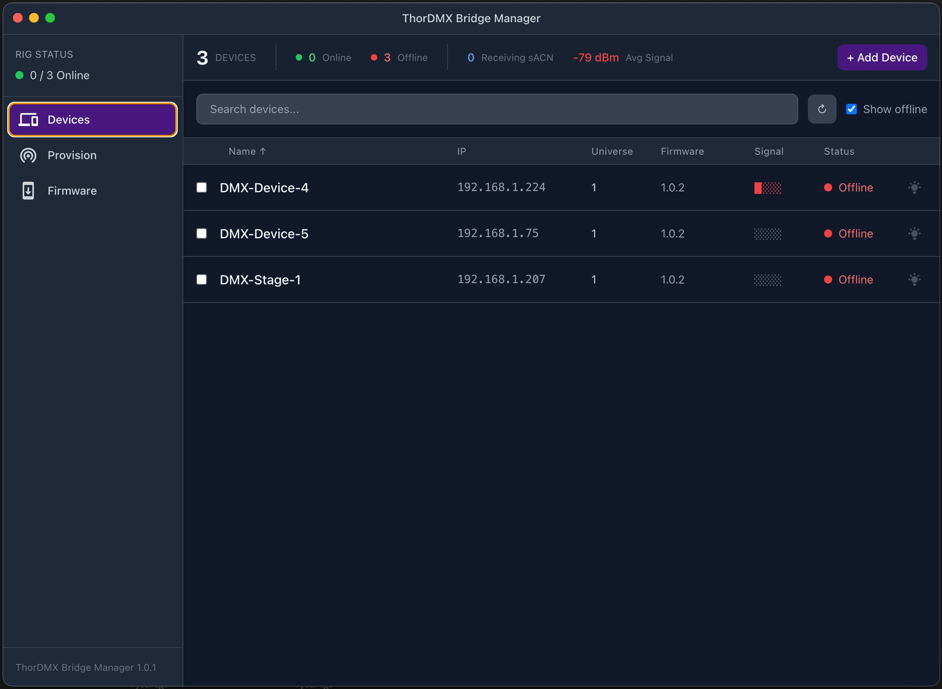
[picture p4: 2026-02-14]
docs/images/screenshot.png

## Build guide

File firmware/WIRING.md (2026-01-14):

# Wiring Guide

Detailed wiring instructions for the sACN to DMX Bridge.

## Components Needed

- ESP32-C6 Development Board
- MAX485 RS-485 Transceiver Module
- WS2812 RGB LED (optional, for status indication)
- 5-pin XLR connector (female) for DMX output
- 120Ω resistor (for DMX termination - optional)
- Power supply (5V USB or external)
- Wire, solder, enclosure

## Pinout

### ESP32-C6 Connections

| ESP32-C6 Pin | Function | Connects To |
|---|---|---|
| GPIO 0 | DMX TX | MAX485 DI (pin 1) |
| GPIO 8 | Status LED | WS2812 Data In |
| GND | Ground | MAX485 GND, WS2812 GND, DMX GND |
| 5V/3.3V | Power | MAX485 VCC (check module voltage) |

### MAX485 Module Connections

| MAX485 Pin | Function | Connects To |
|---|---|---|
| DI | Data In | ESP32-C6 GPIO 0 |
| DE | Driver Enable | 5V or 3.3V (always enabled) |
| RE | Receiver Enable (inverse) | GND (receiver disabled) |
| RO | Receiver Out | Not connected |
| VCC | Power | 5V or 3.3V (match ESP32 output) |
| GND | Ground | ESP32-C6 GND |
| A | Data+ | XLR Pin 3 |
| B | Data- | XLR Pin 2 |

### DMX XLR Connector (Female)

Standard 5-pin XLR connector pinout:

| XLR Pin | Signal | Wire Color (typical) | Connects To |
|---|---|---|---|
| 1 | Ground | Black/Shield | MAX485 GND |
| 2 | Data- | Blue/White | MAX485 B |
| 3 | Data+ | Red/Green | MAX485 A |
| 4 | N/C | - | Not connected |
| 5 | N/C | - | Not connected |

**Note**: 3-pin XLR is also common - use pins 1, 2, 3 only.

## Wiring Diagram (ASCII)

```
                    ┌─────────────────┐
                    │   ESP32-C6      │
                    │                 │
  ┌─────────────────┤ GPIO 0 (TX)     │
  │                 │                 │
  │  ┌──────────────┤ GPIO 8          │───────┐
  │  │              │                 │       │
  │  │         ┌────┤ GND             │──┐    │
  │  │         │    │                 │  │    │
  │  │         │ ┌──┤ 5V/3.3V         │  │    │
  │  │         │ │  └─────────────────┘  │    │
  │  │         │ │                       │    │
  │  │         │ │  ┌─────────────────┐  │    │
  │  │         │ │  │    MAX485       │  │    │
  │  └─────────┼─┼──┤ DI (1)          │  │    │
  │            │ │  │ DE (4) ─────────┼──┘    │
  │            │ │  │ RE (2) ─────────┼───────┤
  │            │ └──┤ VCC             │       │
  │            └────┤ GND             │       │
  │                 │                 │       │
  │            ┌────┤ A (6)           │       │
  │            │    │ B (7)           │       │
  │            │    └─────────────────┘       │
  │            │                              │
  │            │    ┌─────────────────┐       │
  │            │    │   DMX XLR       │       │
  │            ├────┤ Pin 3 (Data+)   │       │
  │            │    │ Pin 2 (Data-)   │       │
  │            │  ┌─┤ Pin 1 (Ground)  │       │
  │            │  │ └─────────────────┘       │
  │            │  │                           │
  │            │  │ ┌─────────────────┐       │
  │            │  │ │   WS2812 LED    │       │
  │            │  │ │ VCC (5V)────────┼───────┘
  │            │  └─┤ GND             │
  └──────────────┼──┤ Data In         │
                 │  └─────────────────┘
                 │
              Common Ground
```

## Step-by-Step Assembly

### 1. Prepare the MAX485 Module

Most MAX485 modules need to be configured for TX-only mode:

1. **Connect DE (Driver Enable) to VCC** (5V or 3.3V)
   - This enables the driver permanently
   - Some modules have a jumper for this

2. **Connect RE (Receiver Enable) to GND**
   - Active low - connecting to ground disables receiver
   - We don't need to receive DMX data

### 2. Wire ESP32-C6 to MAX485

```
ESP32-C6          MAX485
────────          ──────
GPIO 0    ───────> DI
5V        ───────> VCC (check module voltage requirement)
GND       ───────> GND
```

**Important**: Some MAX485 modules work with 3.3V, others need 5V. Check your module's datasheet.

### 3. Wire MAX485 to XLR Connector

```
MAX485            XLR Connector
──────            ─────────────
A         ───────> Pin 3 (Data+, typically red/green wire)
B         ───────> Pin 2 (Data-, typically blue/white wire)
GND       ───────> Pin 1 (Ground, typically black wire)
```

### 4. Add Status LED (Optional)

```
ESP32-C6          WS2812
────────          ──────
GPIO 8    ───────> Data In
5V        ───────> VCC
GND       ───────> GND
```

**Note**: WS2812 requires 5V power. If using 3.3V GPIO, add a level shifter or use a WS2812 compatible with 3.3V logic.

### 5. Power Supply

Connect 5V power to ESP32-C6:
- Via USB-C connector (easiest for development)
- Via VIN pin (for external 5V supply)

**Power Requirements**:
- ESP32-C6: ~200mA (with WiFi active)
- MAX485: ~10mA
- WS2812 LED: ~60mA (at full white)
- **Total**: ~300mA minimum, 500mA recommended

## DMX Cable Specifications

### Cable Type
- Use shielded twisted pair cable
- Characteristic impedance: 120Ω
- Examples:
  - DMX-specific cable (best)
  - Microphone cable (acceptable for short runs)
  - CAT5 ethernet cable (works in a pinch)

### Cable Length
- Maximum recommended: 300 meters (1000 feet)
- For longer runs, use DMX repeater/booster

### Termination
- Last device in DMX chain should have 120Ω terminator
- Connect 120Ω resistor between XLR pins 2 and 3
- Not needed for short cable runs or single fixture

## Testing Connections

### 1. Visual Inspection
- Check all solder joints
- Verify no shorts between A and B lines
- Confirm correct polarity

### 2. Multimeter Tests

**Power Test**:
```
Measure between ESP32 5V and GND: Should read ~5V
Measure between MAX485 VCC and GND: Should read ~5V or ~3.3V
```

**DMX Output Test** (device powered, transmitting):
```
Measure between MAX485 A and B: Should see ~2-5V differential
Measure with oscilloscope: Should see ~250kHz square wave
```

### 3. LED Test
- Power on device
- LED should pulse blue (AP mode)
- If no LED: check wiring, try different GPIO or LED

## Common Wiring Mistakes

| Problem | Cause | Solution |
|---|---|---|
| No DMX output | DE/RE not configured | Tie DE high, RE low |
| Intermittent output | Loose connection | Re-solder all joints |
| DMX A/B swapped | Reversed polarity | Swap pins 2 and 3 on XLR |
| LED doesn't work | Wrong voltage | WS2812 needs 5V |
| ESP32 won't boot | GPIO 0 pulled low at boot | Add 10kΩ pull-up resistor |

## Advanced: PCB Design Considerations

If designing a custom PCB:

1. **Add pull-up on GPIO 0**: 10kΩ to 3.3V (prevents boot issues)
2. **Add decoupling capacitors**:
   - 100nF ceramic near each IC
   - 10µF electrolytic on power supply
3. **Add TVS diodes** on DMX lines for ESD protection
4. **Add indicator LEDs**:
   - Power LED
   - DMX activity LED (on TX line with series resistor)
5. **Add termination option**: Footprint for 120Ω resistor with jumper
6. **Use proper grounding**: Star ground pattern, separate digital/analog grounds

## Enclosure Recommendations

- Use metal or shielded plastic enclosure for EMI protection
- Add ventilation holes (ESP32 can get warm)
- Mount XLR connector securely to chassis
- Use strain relief on all cables
- Label clearly: "DMX OUTPUT", "POWER", etc.

## Safety Notes

⚠️ **Important Safety Information**:

- DMX is low voltage (5V differential) - safe to touch
- Do NOT connect to mains power
- Use proper fuses on power supply
- Ensure proper polarity on all connections
- Test with multimeter before connecting expensive equipment

## Reference Photos

For reference wiring, see similar projects:
- https://github.com/Aircoookie/WLED (WiFi LED controller with similar architecture)
- ESP32 DMX projects on Hackaday.io

---

**Need help?** Check the troubleshooting section in README.md or open an issue.

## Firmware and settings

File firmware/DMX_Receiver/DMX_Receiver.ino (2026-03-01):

/*
 * sACN to DMX Bridge
 * ESP32-C6 Application
 *
 * Receives sACN (E1.31) packets over WiFi and outputs DMX512 signal
 *
 * Hardware:
 * - ESP32-C6 microcontroller
 * - GPIO 1: DMX output (to MAX485 transceiver)
 * - GPIO 8: WS2812 RGB LED for status indication
 */

#include <WiFi.h>
#include <WiFiUdp.h>
#include <WebServer.h>
#include <ESPmDNS.h>
#include <Preferences.h>
#include <ArduinoJson.h>
#include <sACN.h>
#include <FastLED.h>
#include <Update.h>
#include <esp_ota_ops.h>
#include <esp_system.h>
#include <esp_wifi.h>
#include "dmx_driver.h"

// Version
#define FIRMWARE_VERSION "1.1.0"

// Pin definitions
#define DMX_TX_PIN 1
#define LED_PIN 8

// WiFi configuration
#define AP_TIMEOUT_MS 15000
#define SMARTCONFIG_TIMEOUT_MS 120000

// DMX configuration
#define DMX_PACKET_SIZE 512

// LED configuration
#define NUM_LEDS 1

// Global objects
WebServer server(80);
Preferences prefs;
WiFiUDP udp;
Receiver sacn(udp);
CRGB leds[NUM_LEDS];
DMXDriver dmx(DMX_TX_PIN);

// Configuration structure
struct Config
{
  String wifi_ssid;
  String wifi_password;
  String device_name;
  uint16_t sacn_universe;
  uint16_t dmx_start_channel;
} config;

// Runtime state
struct State
{
  bool wifi_connected;
  bool ap_mode_active;
  bool sacn_receiving;
  unsigned long sacn_packets_received;
  unsigned long sacn_packets_errors;
  unsigned long last_packet_time;
  String sacn_source_ip;
  String sacn_source_name;
  uint8_t sacn_priority;
  unsigned long uptime_start;
  unsigned long reboot_count;
  String last_reboot_reason;
  size_t min_free_heap;
  float dmx_fps;
  unsigned long dmx_frame_count;
  unsigned long dmx_fps_last_calc;
} state;

// DMX buffer
uint8_t dmx_data[DMX_PACKET_SIZE];
SemaphoreHandle_t dmx_mutex;

// Task handles
TaskHandle_t wifiTaskHandle = NULL;
TaskHandle_t sacnTaskHandle = NULL;
TaskHandle_t dmxTaskHandle = NULL;
TaskHandle_t ledTaskHandle = NULL;
TaskHandle_t serialTaskHandle = NULL;

// LED state
enum LEDState
{
  LED_OFF,
  LED_AP_MODE,
  LED_CONNECTING,
  LED_CONNECTED,
  LED_ERROR,
  LED_SMARTCONFIG,
  LED_IDENTIFY
};
volatile LEDState led_state = LED_OFF;
volatile unsigned long identify_end_time = 0;

// Forward declarations
void setupWiFi();
void setupAPI();
void loadConfig();
void saveConfig();
String getResetReason();
void wifiTask(void *parameter);
void sacnTask(void *parameter);
void dmxTask(void *parameter);
void ledTask(void *parameter);
void serialTask(void *parameter);
void onDMXFrame();
// captive_portal.ino
void handleCaptivePortal();
void handleCaptivePortalSubmit();
// serial_config.ino
void processSerialCommand(String command);
void handleSerialStatus();
void handleSerialReboot();
void handleSerialFactoryReset();
void handleSerialConfig(String json_str);
// wifi_manager.ino
void startAPMode();
void startMDNS();

void setup()
{
  Serial.begin(115200);

  // Wait for USB-CDC serial to be ready (ESP32-C6 native USB)
  // This ensures we don't miss early boot messages
  unsigned long serial_wait_start = millis();
  while (!Serial && (millis() - serial_wait_start < 3000))
  {
    delay(10);
  }
  delay(500); // Extra delay for serial monitor to attach

  Serial.println("\n\n=================================");
  Serial.println("ThorDMX sACN to DMX Bridge");
  Serial.printf("Firmware: v%s\n", FIRMWARE_VERSION);
  Serial.println("=================================\n");

  // Initialize preferences
  prefs.begin("dmx-bridge", false);

  // Load reboot count and reason
  state.reboot_count = prefs.getULong("reboot_count", 0) + 1;
  prefs.putULong("reboot_count", state.reboot_count);
  state.last_reboot_reason = getResetReason();

  // Initialize state
  state.wifi_connected = false;
  state.sacn_receiving = false;
  state.sacn_packets_received = 0;
  state.sacn_packets_errors = 0;
  state.last_packet_time = 0;
  state.sacn_priority = 0;
  state.uptime_start = millis();
  state.min_free_heap = ESP.getFreeHeap();
  state.dmx_fps = 0;
  state.dmx_frame_count = 0;
  state.dmx_fps_last_calc = millis();

  // Load configuration
  loadConfig();

  Serial.printf("Device Name: %s\n", config.device_name.c_str());
  Serial.printf("sACN Universe: %d\n", config.sacn_universe);
  Serial.printf("DMX Start Channel: %d\n", config.dmx_start_channel);

  // Initialize DMX buffer
  memset(dmx_data, 0, DMX_PACKET_SIZE);
  dmx_mutex = xSemaphoreCreateMutex();

  // Initialize custom DMX driver
  if (!dmx.begin())
  {
    Serial.println("[DMX] Failed to initialize DMX driver!");
  }
  else
  {
    Serial.println("[DMX] DMX driver initialized");
  }

  // Initialize LED
  FastLED.addLeds<WS2812, LED_PIN, GRB>(leds, NUM_LEDS);
  FastLED.setBrightness(50);
  leds[0] = CRGB::Black;
  FastLED.show();

  // Create tasks (ESP32-C6 is single-core, use core 0 for all)
  xTaskCreate(wifiTask, "WiFi", 4096, NULL, 1, &wifiTaskHandle);
  xTaskCreate(sacnTask, "sACN", 4096, NULL, 2, &sacnTaskHandle);
  xTaskCreate(dmxTask, "DMX", 3072, NULL, 3, &dmxTaskHandle);
  xTaskCreate(ledTask, "LED", 2048, NULL, 0, &ledTaskHandle);
  xTaskCreate(serialTask, "Serial", 3072, NULL, 1, &serialTaskHandle);

  Serial.println("Initialization complete\n");
}

void loop()
{
  // Main loop handles web server (both AP mode and station mode)
  if (state.wifi_connected || state.ap_mode_active)
  {
    server.handleClient();
  }

  // Track minimum free heap
  size_t free_heap = ESP.getFreeHeap();
  if (free_heap < state.min_free_heap)
  {
    state.min_free_heap = free_heap;
  }

  delay(10);
}

void loadConfig()
{
  config.wifi_ssid = prefs.getString("wifi_ssid", "");
  config.wifi_password = prefs.getString("wifi_pass", "");
  config.sacn_universe = prefs.getUShort("sacn_universe", 1);
  config.dmx_start_channel = prefs.getUShort("dmx_start_ch", 1);

  // Generate device name from MAC if not set
  String saved_name = prefs.getString("device_name", "");
  if (saved_name.length() == 0)
  {
    uint8_t mac[6];
    WiFi.macAddress(mac);
    config.device_name = String("DMX-Bridge-") +
                         String(mac[4], HEX) + String(mac[5], HEX);
    config.device_name.toUpperCase();
  }
  else
  {
    config.device_name = saved_name;
  }
}

void saveConfig()
{
  prefs.putString("wifi_ssid", config.wifi_ssid);
  prefs.putString("wifi_pass", config.wifi_password);
  prefs.putString("device_name", config.device_name);
  prefs.putUShort("sacn_universe", config.sacn_universe);
  prefs.putUShort("dmx_start_ch", config.dmx_start_channel);
}

String getResetReason()
{
  esp_reset_reason_t reason = esp_reset_reason();
  switch (reason)
  {
  case ESP_RST_POWERON:
    return "power_on";
  case ESP_RST_SW:
    return "software";
  case ESP_RST_PANIC:
    return "crash";
  case ESP_RST_INT_WDT:
    return "watchdog";
  case ESP_RST_TASK_WDT:
    return "watchdog";
  case ESP_RST_WDT:
    return "watchdog";
  case ESP_RST_BROWNOUT:
    return "brownout";
  default:
    return "unknown";
  }
}

String getMacAddress()
{
  uint8_t mac[6];
  WiFi.macAddress(mac);
  char macStr[18];
  snprintf(macStr, sizeof(macStr), "%02X:%02X:%02X:%02X:%02X:%02X",
           mac[0], mac[1], mac[2], mac[3], mac[4], mac[5]);
  return String(macStr);
}

String getSignalQuality(int rssi)
{
  if (rssi > -50)
    return "excellent";
  if (rssi > -60)
    return "good";
  if (rssi > -70)
    return "fair";
  return "poor";
}

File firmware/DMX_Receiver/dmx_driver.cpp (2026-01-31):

/*
 * Custom DMX512 Driver for ESP32-C6
 * Uses UART baud rate switching for break generation
 * No interrupt disabling — WiFi-safe
 */

#include "dmx_driver.h"

DMXDriver::DMXDriver(int tx_pin) : _tx_pin(tx_pin), _initialized(false) {}

bool DMXDriver::begin() {
  // Configure UART for DMX512: 250kbaud, 8N2
  uart_config_t uart_config = {
      .baud_rate = DMX_BAUD_RATE,
      .data_bits = UART_DATA_8_BITS,
      .parity = UART_PARITY_DISABLE,
      .stop_bits = UART_STOP_BITS_2,
      .flow_ctrl = UART_HW_FLOWCTRL_DISABLE,
      .source_clk = UART_SCLK_DEFAULT,
  };

  // Install UART driver with ISR in IRAM to prevent WiFi interrupt latency
  // from causing TX FIFO underruns
  esp_err_t err = uart_driver_install(DMX_UART_NUM, 256, 1024, 0, NULL,
                                      ESP_INTR_FLAG_IRAM);
  if (err != ESP_OK) {
    Serial.printf("[DMX] uart_driver_install failed: %d\n", err);
    return false;
  }

  // Configure UART parameters
  err = uart_param_config(DMX_UART_NUM, &uart_config);
  if (err != ESP_OK) {
    Serial.printf("[DMX] uart_param_config failed: %d\n", err);
    uart_driver_delete(DMX_UART_NUM);
    return false;
  }

  // Set UART TX pin
  err = uart_set_pin(DMX_UART_NUM, _tx_pin, UART_PIN_NO_CHANGE,
                     UART_PIN_NO_CHANGE, UART_PIN_NO_CHANGE);
  if (err != ESP_OK) {
    Serial.printf("[DMX] uart_set_pin failed: %d\n", err);
    uart_driver_delete(DMX_UART_NUM);
    return false;
  }

  _initialized = true;
  Serial.printf("[DMX] Initialized on GPIO %d\n", _tx_pin);
  return true;
}

void DMXDriver::sendPacket(const uint8_t* data, size_t length) {
  if (!_initialized) return;

  size_t send_length = (length > 512) ? 512 : length;

  // Wait for any previous transmission to complete
  uart_wait_tx_done(DMX_UART_NUM, pdMS_TO_TICKS(30));

  // Generate BREAK + MAB using slow baud rate
  // Sending 0x00 at 90000 baud (8N2): 9 low bits = 100µs BREAK, 2 high bits = 22µs MAB
  uart_set_baudrate(DMX_UART_NUM, DMX_BREAK_BAUD);
  uint8_t break_byte = 0x00;
  uart_write_bytes(DMX_UART_NUM, &break_byte, 1);
  uart_wait_tx_done(DMX_UART_NUM, pdMS_TO_TICKS(30));

  // Switch back to DMX baud rate for data
  uart_set_baudrate(DMX_UART_NUM, DMX_BAUD_RATE);

  // Build complete frame: start code + channel data
  // Single write prevents any gap between start code and data
  _frame[0] = 0x00;
  memcpy(_frame + 1, data, send_length);
  uart_write_bytes(DMX_UART_NUM, _frame, send_length + 1);

  // Wait for transmission to complete
  uart_wait_tx_done(DMX_UART_NUM, pdMS_TO_TICKS(30));
}

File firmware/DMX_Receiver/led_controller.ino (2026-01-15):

/*
 * LED Status Controller Task
 * Manages WS2812 LED to indicate device state
 */

void ledTask(void* parameter) {
  uint8_t pulse_brightness = 0;
  bool pulse_direction = true;

  while (true) {
    switch (led_state) {
      case LED_OFF:
        leds[0] = CRGB::Black;
        FastLED.show();
        break;

      case LED_AP_MODE:
        // Pulsing blue (1 second cycle)
        if (pulse_direction) {
          pulse_brightness += 5;
          if (pulse_brightness >= 200) pulse_direction = false;
        } else {
          pulse_brightness -= 5;
          if (pulse_brightness <= 30) pulse_direction = true;
        }
        leds[0] = CRGB(0, 0, pulse_brightness);
        FastLED.show();
        vTaskDelay(pdMS_TO_TICKS(20));
        break;

      case LED_CONNECTING:
        // Pulsing yellow (0.5 second cycle)
        if (pulse_direction) {
          pulse_brightness += 10;
          if (pulse_brightness >= 200) pulse_direction = false;
        } else {
          pulse_brightness -= 10;
          if (pulse_brightness <= 30) pulse_direction = true;
        }
        leds[0] = CRGB(pulse_brightness, pulse_brightness / 2, 0);
        FastLED.show();
        vTaskDelay(pdMS_TO_TICKS(10));
        break;

      case LED_CONNECTED:
        // Solid green for 2 seconds
        leds[0] = CRGB::Green;
        FastLED.show();
        vTaskDelay(pdMS_TO_TICKS(2000));
        led_state = LED_OFF;
        break;

      case LED_ERROR:
        // Solid red
        leds[0] = CRGB::Red;
        FastLED.show();
        vTaskDelay(pdMS_TO_TICKS(100));
        break;

      case LED_SMARTCONFIG:
        // Same as AP mode (pulsing blue)
        if (pulse_direction) {
          pulse_brightness += 5;
          if (pulse_brightness >= 200) pulse_direction = false;
        } else {
          pulse_brightness -= 5;
          if (pulse_brightness <= 30) pulse_direction = true;
        }
        leds[0] = CRGB(0, 0, pulse_brightness);
        FastLED.show();
        vTaskDelay(pdMS_TO_TICKS(20));
        break;

      case LED_IDENTIFY:
        // Fast flashing white/magenta for identification
        if (millis() < identify_end_time) {
          // Alternate between white and magenta every 200ms
          if ((millis() / 200) % 2 == 0) {
            leds[0] = CRGB::White;
          } else {
            leds[0] = CRGB::Magenta;
          }
          FastLED.show();
          vTaskDelay(pdMS_TO_TICKS(50));
        } else {
          // Identify period ended, turn off
          led_state = LED_OFF;
        }
        break;
    }

    vTaskDelay(pdMS_TO_TICKS(10));
  }
}

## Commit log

2026-01-16 fixed dmx output without stopping other services
    [dmx_driver.cpp, dmx_output.ino]
2026-01-17 device list combine
2026-01-20 device remove, stored devices list
2026-01-21 multi-device config
2026-01-31 fixpacket loss, frame rate slowdown and wifi disconnections
    [DMX_Receiver.ino, dmx_driver.cpp, sacn_receiver.ino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]
2026-02-14 updated docs + gerbers
    [dmx_rec-B_Cu.gbr, dmx_rec-B_Mask.gbr, dmx_rec-B_Paste.gbr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]
2026-03-01 updated color wheel
